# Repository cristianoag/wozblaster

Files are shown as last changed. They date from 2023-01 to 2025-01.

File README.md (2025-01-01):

# The Wozblaster (Reloaded)

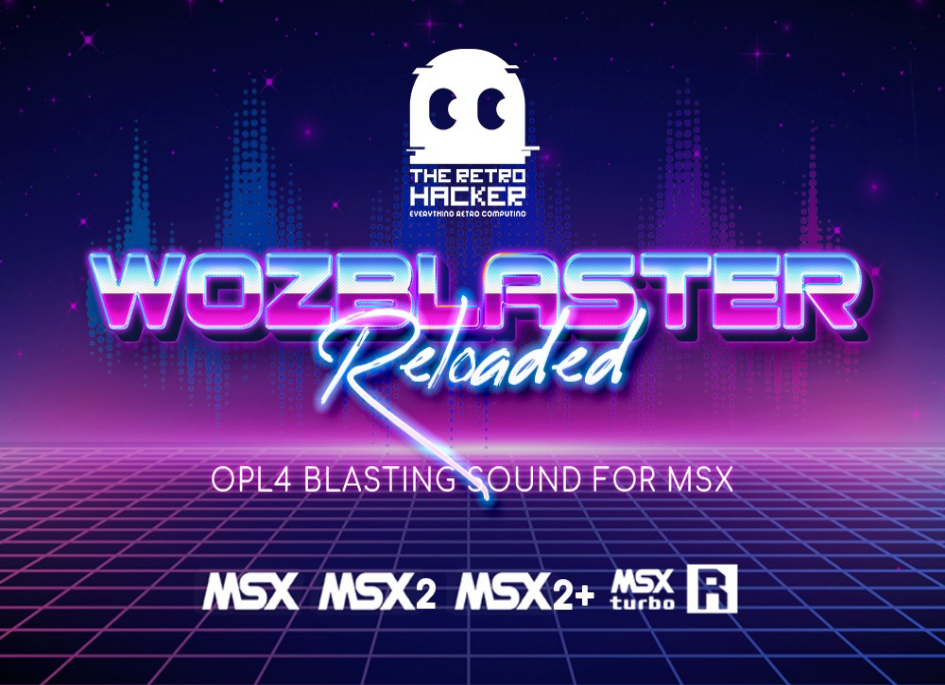
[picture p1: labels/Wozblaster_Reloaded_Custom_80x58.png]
Label


## Introduction 
The WozBlaster OPL4 cartridge is a sound expansion device designed for the MSX platform. This cartridge enables a range of additional audio capabilities for the MSX, including support for both FM synthesis and wavetable synthesis. 

At its core is the OPL4 (FM Operator Type-L4) sound chip, which was developed by Yamaha and used in a variety of electronic musical instruments and computer sound cards. 

With the WozBlaster OPL4 cartridge, MSX computer users can enjoy high-quality sound and create complex musical arrangements with ease.

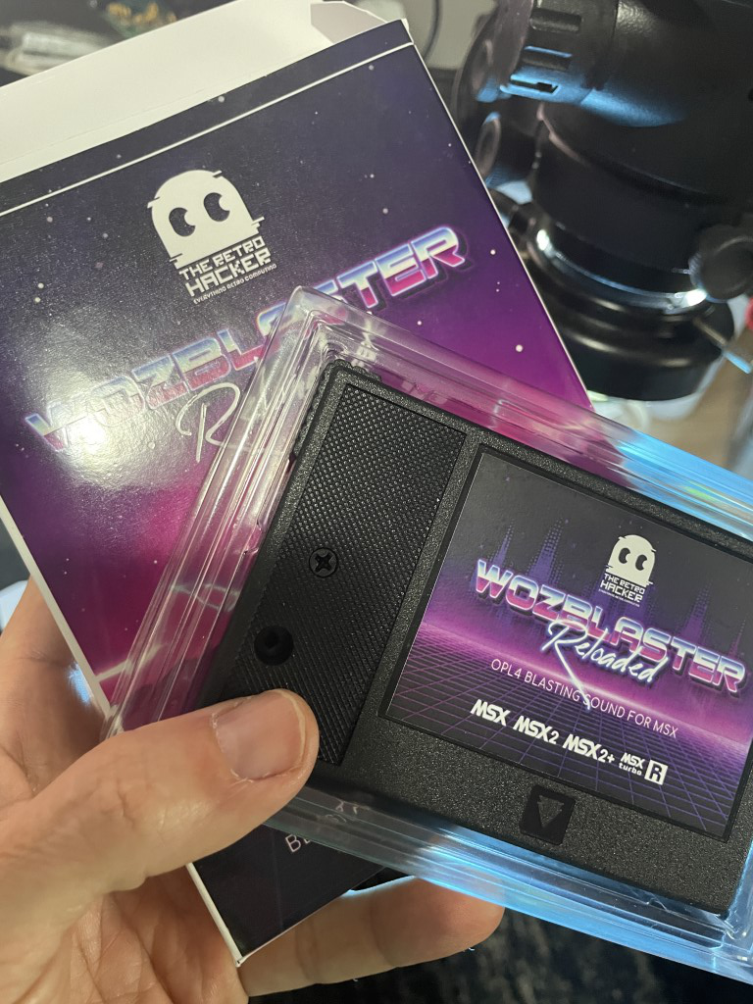
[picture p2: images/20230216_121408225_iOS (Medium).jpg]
The Wozblaster Reloaded Cartridge


The WozBlaster cartridge is an external sound device designed for the MSX platform. It is a clone of the Moonsound and allows access to the advanced capabilities of the OPL4 sound chip for MSX games and other OPL4-compatible music software. The cartridge was originally designed by Gustavo Iriarte.

The OPL4 sound chip from Yamaha is typically paired with a YAC513 floating-point DAC chip, or an alternative compatible DAC chip. The YMF278 is an enhanced version of the OPL3 and, although not officially part of the standard, has been widely adopted by the MSX community, particularly in Europe.

Moonsound clones generally come equipped with 1 MB of sample-RAM and a 2 MB Yamaha YRW801-M General MIDI ROM. Although the board has the capacity to address more than 1 MB of memory, the original version of the Wozblaster only had two 512K memory chips.

It's worth noting that the original Wozblaster PCB cannot be fitted into a traditional MSX cartridge case. Additionally, as detailed in the building instructions, the audio jack holes on the original board are quite small, which made it difficult to find a connector that would fit.

## Original Wozblaster

Image below shows the original Wozblaster cartridge PCB:

|PCB Side 1|PCB Side 2|
|---|---|
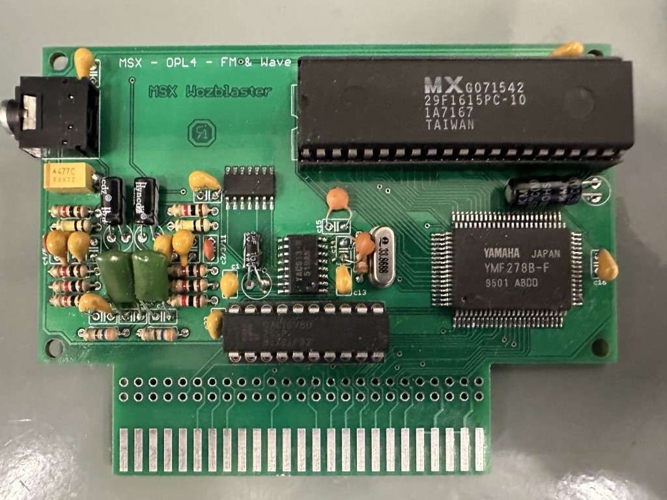
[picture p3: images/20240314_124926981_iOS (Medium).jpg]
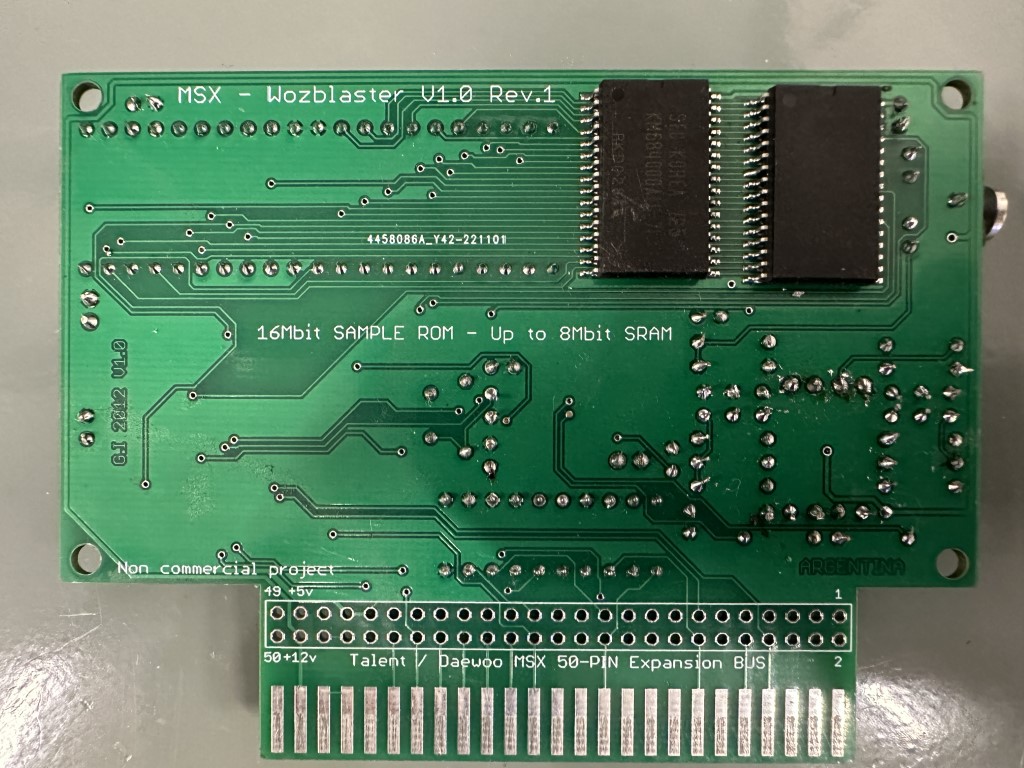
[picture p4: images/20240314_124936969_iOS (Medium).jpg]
|||

A few reloaded versions of the WozBlaster cartridge have been created with appropriately-sized holes to fit both Konami and Patola cartridge cases. Additionally, the audio jack holes have been enlarged to accommodate most common audio jack connectors. Some versions of the cartridge are still a work in progress.

## Reloaded Versions

Currently, the following versions of the WozBlaster cartridge are available (please note that this list is subject to change as new versions become available):

* [Wozblaster Reloaded v1.1](/hardware/reloaded_v1.1) - Based on the original circuit, this version features a combination of through-hole and surface-mount components. The board is smaller and can fit in both Konami and Patola cases. (tested and working)

|PCB Side 1|PCB Side 2|
|---|---|
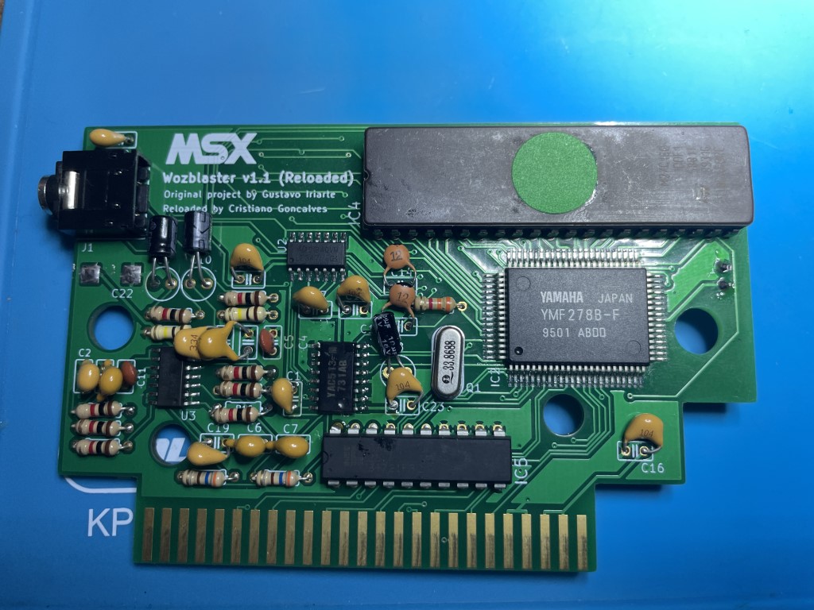
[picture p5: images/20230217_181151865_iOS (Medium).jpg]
The Wozblaster Reloaded PCB
||The Wozblaster Reloaded PCB|

* [Wozblaster Reloaded v1.3](/hardware/reloaded_v1.3) - This version replaces the old 27C160 EPROM with an AM29F016B flash memory, and all passive components are 0603 SMD. The sound is injected back to SOUNDIN in mono. The board is smaller and can fit in both Konami and Patola cases. (abandoned)
  
* [Wozblaster Reloaded v3.3](/hardware/reloaded_v3.3/) - Version based on the UDA1334 DAC, and using the [Adafruit A1334 DAC Module](https://github.com/adafruit/Adafruit-UDA1334A-I2S-Stereo-DAC-PCB) to perform the digital to analog conversion. It is injecting audio back into the SOUNDIN MSX pin. It features 1MB of RAM and 2MB of ROM with MIDI compatible samples. (tested and working)

|PCB Side 1|PCB Side 2|
|---|---|
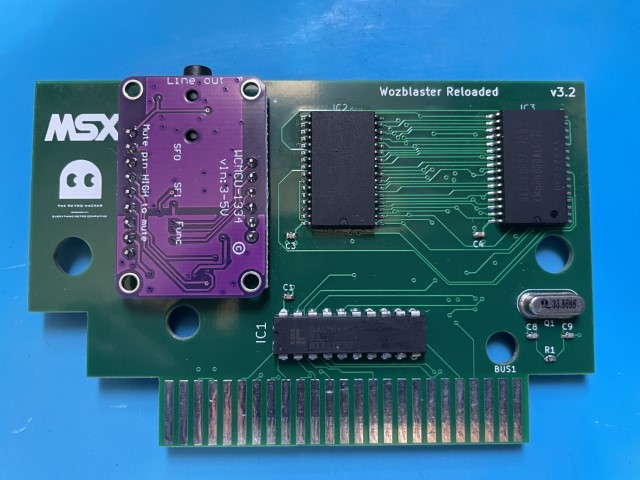
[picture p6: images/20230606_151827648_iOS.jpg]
The Wozblaster Reloaded 3.3 PCB Side 1
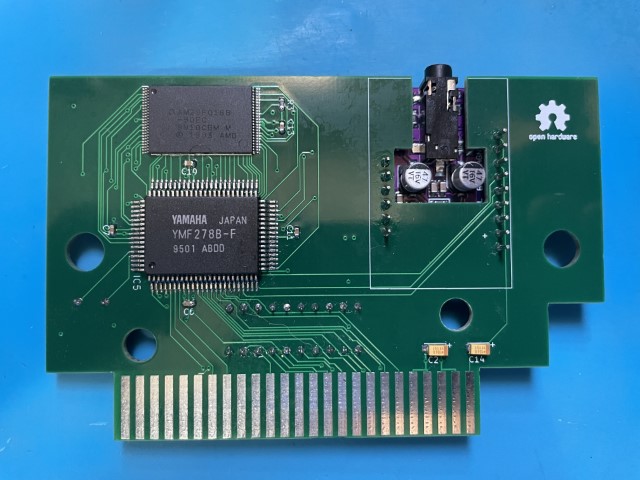
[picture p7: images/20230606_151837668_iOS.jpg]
The Wozblaster Reloaded 3.3 PCB Side 2
|||

* [Wozblaster Reloaded v4.0](/hardware/reloaded_v4.0/) - Evolution of v3.3 featuring a 2MB CY62167ELL RAM integrated. It also mixes the computer SOUNDIN. (tested and working)

|PCB Side 1|PCB Side 2|
|---|---|
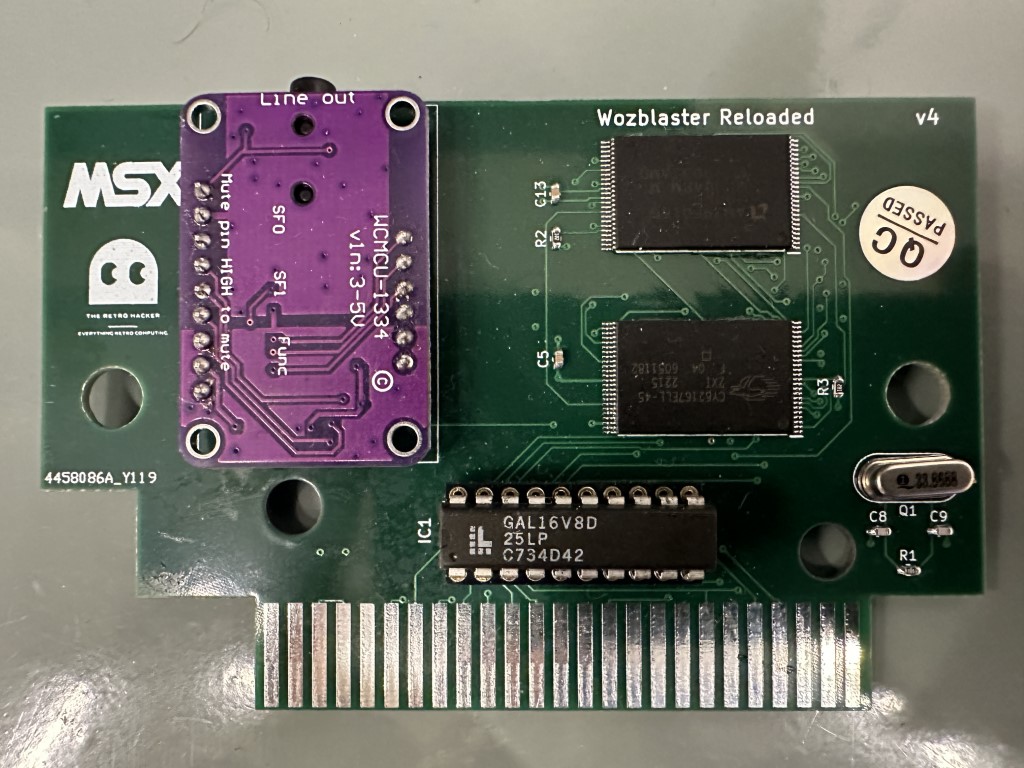
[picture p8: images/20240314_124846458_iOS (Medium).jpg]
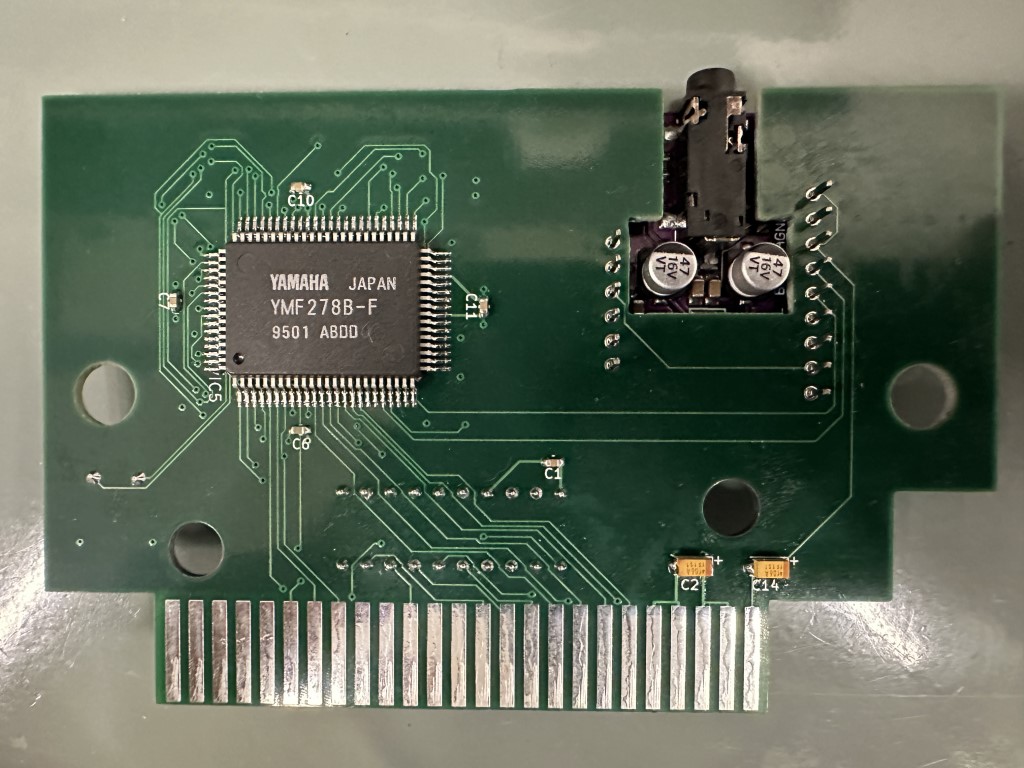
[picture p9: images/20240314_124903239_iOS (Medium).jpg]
|||

* [Wozblaster Reloaded v4.5](/hardware/reloaded_v4.5/) - This version is now using the EPM7064STC44 (or EPM7032STC400) CPLD to replace the GAL16V8D it also better isolates the audio channels  before injecting them as mono back to the MSX SOUNDIN. (tested and working)

|PCB Side 1|PCB Side 2|
|---|---|
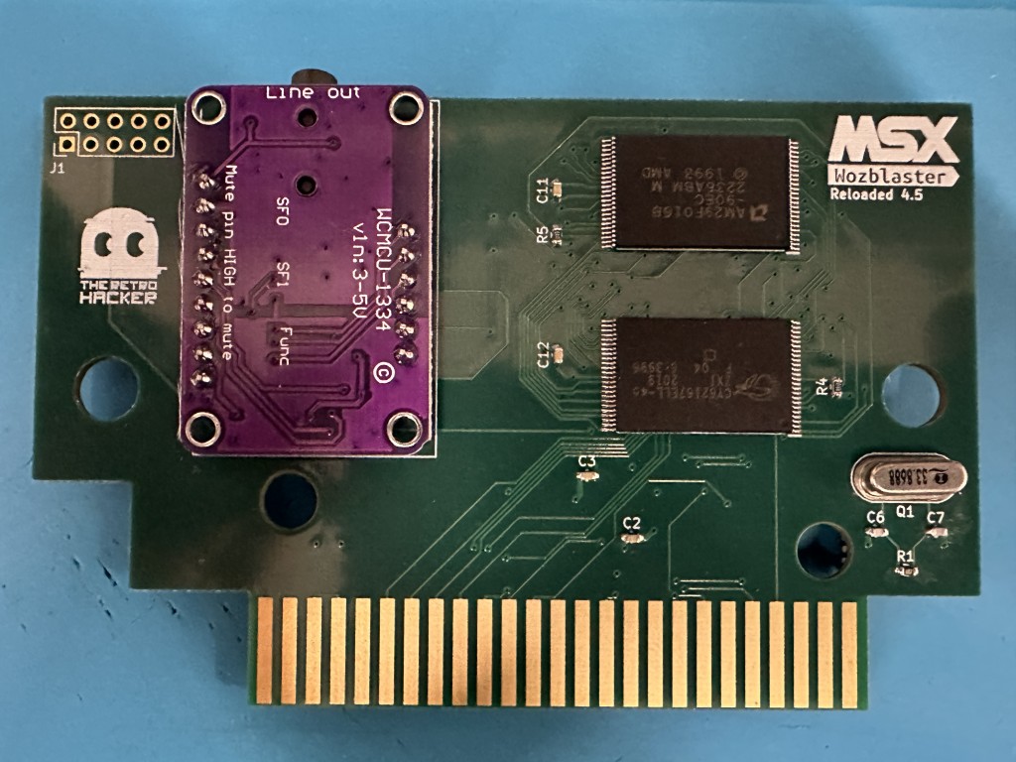
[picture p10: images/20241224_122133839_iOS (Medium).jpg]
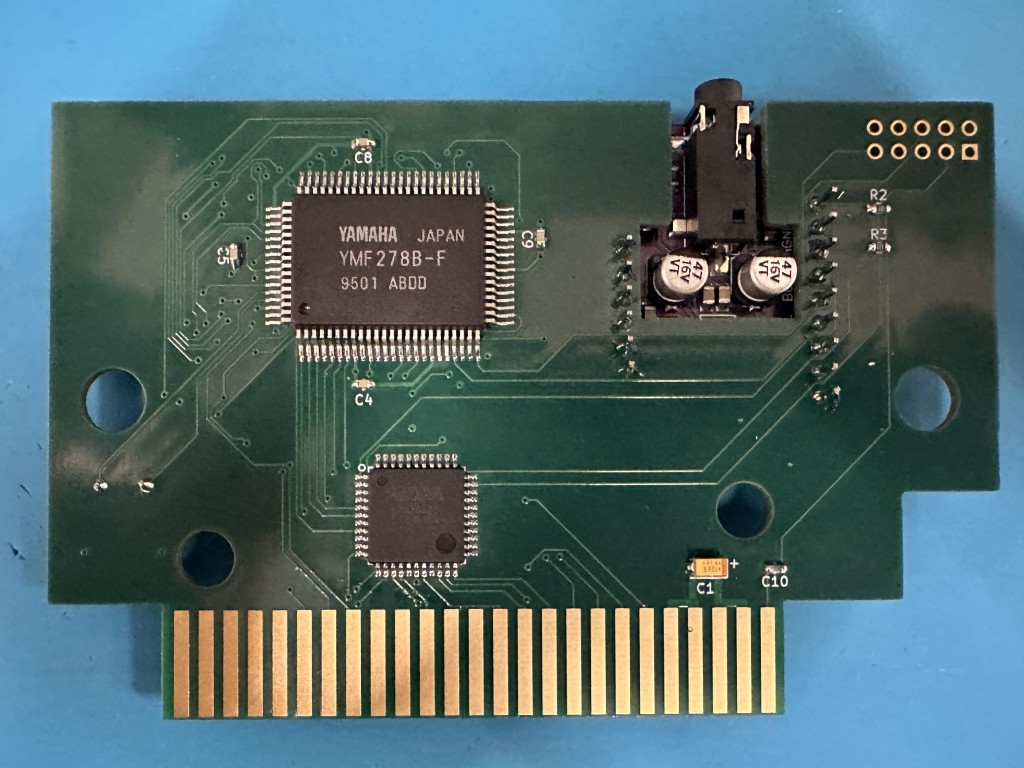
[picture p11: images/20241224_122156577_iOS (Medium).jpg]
|||

## Bill of Materials

The Bill of Materials (BOM) for each version of the WozBlaster cartridge is available in the respective page. The BOM includes a list of all the components needed to build the cartridge, as well as links to purchase the components online.

## Box and Inlay Trays

The Wozblaster Reloaded has a box designed by Adriano Souza to fit the cartridge. The box is available in the [box](/box) folder.

Although a paper inlay is provided to secure the cartridge inside the box, it is  recommended to use a plastic insert inner tray (bed) for additional protection, especially during transportation. These trays can be purchased from AliExpress at the following link: [AliExpress Tray](https://s.click.aliexpress.com/e/_DDVBv2D).

## Resources

This GitHub repository contains all of the resources needed to build both the original WozBlaster cartridge and the reloaded versions. For detailed instructions, you can refer to the article I wrote, which includes an updated bill of materials (BOM) with links to purchase the required components. You can find the article at https://theretrohacker.com/2022/12/31/blasting-sound-for-your-msx-the-wozblaster-reloaded/.

The update on the v3.1 development has been posted on a short YouTube video in english [here](https://youtu.be/J95RrFSF2NM). 

The update on v3.2 is available on a quick video [here](https://www.youtube.com/shorts/V5VmL33uvzE). 

Each folder contains detailed Bill of Materials for each version of the board, as well as the Gerber files needed to manufacture the PCBs. 

## License 

Open Hardware

This work is licensed under a [Creative Commons Attribution-NonCommercial-ShareAlike 4.0 International License](http://creativecommons.org/licenses/by-nc-sa/4.0/).

* If you remix, transform, or build upon the material, you must distribute your contributions under the same license as the original.
* You may not use the material for commercial purposes.
* You must give appropriate credit, provide a link to the license, and indicate if changes were made. You may do so in any reasonable manner, but not in any way that suggests the licensor endorses you or your use.

**ATTENTION**

This project was made for the retro community and not for commercial purposes. So only retro hardware forums and individual people can build this project.

THE SALE OF ANY PART OF THIS PROJECT WITHOUT EXPRESS AUTHORIZATION IS PROHIBITED!

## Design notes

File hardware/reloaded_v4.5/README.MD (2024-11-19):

# The Wozblaster Reloaded v4.5

- Interactive bill of materials: [BOM](https://htmlpreview.github.io/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)
- Adafruit UDA1334 module - https://github.com/adafruit/Adafruit-UDA1334A-I2S-Stereo-DAC-PCB
- Gerber Files [MSX_OPL4_Wozblaster_Reloaded_4.5.zip](/MSX%20OPL4%20Wozblaster/production/MSX_OPL4_Wozblaster_Reloaded_5.0.zip)

## Bill of Materials - Purchase List

|References|Value|Footprint|Quantity|Link|
|---|-----|---|---|----|
|C2, C3, C4, C5, C8, C9, C11, C12|0.1uF|C_0603_1608Metric|	8|[Ali Express](https://s.click.aliexpress.com/e/_DmZ8Brh)|
|C6, C7|12pF	|C_0603_1608Metric	|2|[Ali Express](https://s.click.aliexpress.com/e/_DmZ8Brh)|
|C1|	10uF/10v	|CP_EIA-3216-18_Kemet-A|	1|[Ali Express](https://s.click.aliexpress.com/e/_DDWaCDp)|
|R2, R3	|330R|R_0603_1608Metric	|2|[Ali Express](https://s.click.aliexpress.com/e/_DDKvQnz)|
|R4, R5	|1K	|R_0603_1608Metric	|5|[Ali Express](https://s.click.aliexpress.com/e/_DDKvQnz)|
|R1	|3.3K|	R_0603_1608Metric	|1|[Ali Express](https://s.click.aliexpress.com/e/_DDKvQnz)|
|U1|EPM7064STC44-7 (or EPM7032STC44)|QFP80P1200X1200X120-44N	|1|[Ali Express](https://s.click.aliexpress.com/e/_DkdMPh3)|
|U2	|UDA1334MOD	|UDA1334MOD	|1|[Ali Express](https://www.aliexpress.com/item/1005003524298218.html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)|
|U3	|YMF278B-F|	80-QFP|1|[The Retro Hacker Store](https://theretrohacker.com/shop)|
|U4	|AM29F016B-120EC|	SOP50P2000X120-48N	|1|[Ali Express](https://s.click.aliexpress.com/e/_Dm44l5V)|
|U5	|CY62167ELL|	SOP50P2000X120-48N	|1|[Ali Express](https://s.click.aliexpress.com/e/_DkopT8T)|
|Q1	|33.8688|	Crystal_HC49-U_Vertical|1|[Ali Express](https://s.click.aliexpress.com/e/_DlvdCQT)|
|J1|AVR-JTAG-10	|PinHeader_2x05_P2.54mm_Vertical	|1|[Ali Express](https://s.click.aliexpress.com/e/_DFQLUzR)|

## CPLD Code

The Wozblaster Reloaded 4.5 uses a EPM7064STC44 (or EPM7032STC44) CPLD. The code is available in the `cpld` folder. The code was written in Verilog and compiled using the Quartus II software. The compiled file `msx_opl4.pof` is also available in the `cpld` folder. Please use the appropriate version depending on the CPLD you selected.

It implements the selection of the OPL4 chip and its registers. 

The I/O of the OPL4 can be done on the following I/O ports:

|Port|Binary|Function|
|-----|---|----|
|07Eh |01111110 | wave register	|
|07Fh |01111111 | wave data|				
|0C4h |11000100 | FM bank 1 register|
|0C5h |11000101 | FM data|
|0C6h |11000110 | FM bank 2 register|

0C7h is a mirror of the FM data register but use of 0C5h is preferred.

The selection of the EPM7064STC44 (or EPM7032STC44) CPLD was due to the fact that it is a common CPLD supporting 5V and can be found in several sources. It is also less subject to JTAG locking than other versions of those CPLDs based on PLCC. The 
EPM7032STC44 can also be used as it is pin compatible with the EPM7064STC44 and the size of synthesis is small enough to fit in the EPM7032STC44.

## SOUNDIN

The SOUNDIN signal for the MSX computer is obtained by combining the two stereo channels into a single mono channel over a set of resistors a a filter capacitor. 

## License
Open Hardware

This work is licensed under a [Creative Commons Attribution-NonCommercial-ShareAlike 4.0 International License](http://creativecommons.org/licenses/by-nc-sa/4.0/).

* If you remix, transform, or build upon the material, you must distribute your contributions under the same license as the original.
* You may not use the material for commercial purposes.
* You must give appropriate credit, provide a link to the license, and indicate if changes were made. You may do so in any reasonable manner, but not in any way that suggests the licensor endorses you or your use.

**ATTENTION**

This project was made for the retro community and not for commercial purposes. So only retro hardware forums and individual people can build this project.

THE SALE OF ANY PART OF THIS PROJECT WITHOUT EXPRESS AUTHORIZATION IS PROHIBITED!

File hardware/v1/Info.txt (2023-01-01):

Wozblaster V1.0 Rev.1

Se corrigió:

- Texto erróneo +5V / +12v que estaban invertidos.
- Se corrió 1mm hacia borde perforación masa jack audio.
- Texto c2/3/12 por c2/3/11.

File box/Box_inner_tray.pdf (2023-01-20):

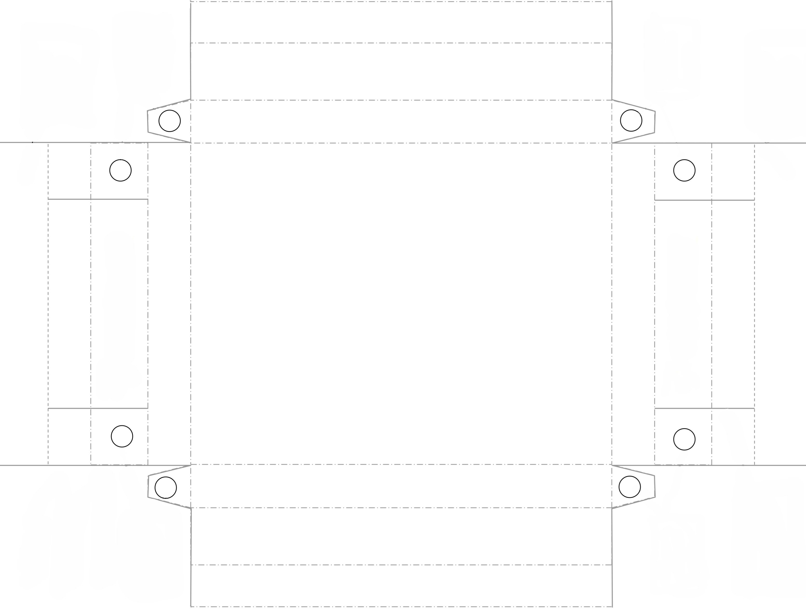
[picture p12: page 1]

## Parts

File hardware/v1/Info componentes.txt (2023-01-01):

100nF ceramico

c13
c16
c17
c19
c18
c20
c23

---------------------

4.7uF 16v

c21

---------------------

10uF x 16v

c8

---------------------

22uF x 16v

c9
c10

---------------------

12p ceramico

c14
c15

---------------------

10p ceramico

c1

---------------------

2200p ceramico

c6
c7
c5
c3

---------------------

0.015uF ceramico

c4
c11

---------------------

0.33uF ceramico

c12
c2

---------------------

470uF x 16v

c22

---------------------

OPL4: Yamaha YMF278B-F

DAC: Yamaha YAC513-M

Op-Amps: LF347

SRAM: KM684000ALG

EPROM: 27c160

GAL: Lattice 16V8D

Cristal: 33.8688

1 Jack audio stereo

---------------------

8r x 1K
2r x 360ohm
2r x 100k
1r x 3.3k

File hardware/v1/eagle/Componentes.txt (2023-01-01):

List of components:

1 x PCB
1 x YMF278B-F or YMF268-F
1 x YAC513-M (SOP16)
2 x LF347 (SOP14)
1 x GAL16V8D (DIP20)
1 x 27C160 EPROM (DIP42)
2 x KM684000ALG (512kB) (SOP32)
1 x Cristal 33.8688 (HC49-S)
7 x 100nF cerámic / multilayer  2.5 mm or less
4 x 2200pF cerámic 2.5 mm or less
2 x 12pF cerámic  2.5 mm or less
1 x 10pF cerámic  2.5 mm or less
2 x 0.015uF cerámic  2.5 mm or less
2 x 0.033uF cerámic  2.5 mm or less
1 x 3.3K 1/4
8 x 1K 1/4
2 x 100K 1/4
2 x 360ohm 1/4
1 x 4.7uF 16v 
1 x 10uF 16v  
2 x 22uF 16v  
1 x Jack Audio Estereo para chasis 1/4
C22,470uFx16v tantalum not necessary.

Avoid use of used 27c160, try to use only new ones due to programming failure.

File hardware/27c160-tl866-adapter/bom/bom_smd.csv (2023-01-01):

Component | Part | References | Value | MPN | Quantity Per PCB | Datasheet
1 | BC327 | Q1 | MMBT3906 | MMBT3906-7-F | 1 | https://media.digikey.com/pdf/Data%20Sheets/Diodes%20PDFs/MMBT3906.pdf
2 | R-EU_0207_10 | R1 R2 R3 R4 R5 | 10k | RC1206JR-0710KP | 5 | http://www.yageo.com/NewPortal/yageodocoutput?fileName=/pdf/R-Chip/PYu-RC_51_RoHS_P_0.pdf
3 | SW_DIP-3 | SW2 | DIP | BD03 | 1 | https://www.ckswitches.com/media/1331/bd.pdf
4 | MS22D16 | SW1 | MS22D16 | JS202011CQN | 1 | https://www.ckswitches.com/media/1422/js.pdf
5 | 27C4002 | U1 | 27C4002 | 61302011121 | 2 | https://katalog.we-online.de/em/datasheet/6130xx11121.pdf
6 | 3M_248-3345 | ZX1 | 3M_248-3345 | 248-1282-00-0602J | 1 | http://multimedia.3m.com/mws/media/494546O/3mtm-dip-sockets-100-2-54-mm-ts0365.pdf

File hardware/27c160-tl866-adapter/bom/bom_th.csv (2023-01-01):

Component | Part | References | Value | MPN | Quantity Per PCB | Datasheet
1 | BC327 | Q1 | BC327 | BC327 | 1 | https://media.digikey.com/pdf/Data%20Sheets/ON%20Semiconductor%20PDFs/BC327%20Rev3.pdf
2 | R-EU_0207_10 | R1 R2 R3 R4 R5 | 10k | CFR-25JB-52-10K | 5 | http://www.yageo.com/NewPortal/yageodocoutput?fileName=/pdf/throughhole/Yageo_LR_CFR_2013.pdf
3 | SW_DIP-3 | SW2 | DIP | BD03 | 1 | https://www.ckswitches.com/media/1331/bd.pdf
4 | MS22D16 | SW1 | MS22D16 | JS202011CQN | 1 | https://www.ckswitches.com/media/1422/js.pdf
5 | 27C4002 | U1 | 27C4002 | 61302011121 | 2 | https://katalog.we-online.de/em/datasheet/6130xx11121.pdf
6 | 3M_248-3345 | ZX1 | 3M_248-3345 | 248-1282-00-0602J | 1 | http://multimedia.3m.com/mws/media/494546O/3mtm-dip-sockets-100-2-54-mm-ts0365.pdf

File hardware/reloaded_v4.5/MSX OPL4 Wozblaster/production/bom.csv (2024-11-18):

Designator | Footprint | Quantity | Value | LCSC Part #
C1 | CP_EIA-3216-18_Kemet-A | 1 | 10uF/10v
C10 | 0603 | 1 | 10uF
C11, C12, C2, C3, C4, C5, C8, C9 | 0603 | 8 | 0.1uF
C6, C7 | 0603 | 2 | 12pF
J1 | PinHeader_2x05_P2.54mm_Vertical | 1 | AVR-JTAG-10
Q1 | Crystal_HC49-U_Vertical | 1 | 33.8688
R1 | 0603 | 1 | 3.3K
R2, R3 | 0603 | 2 | 330R
R4, R5 | 0603 | 2 | 1K
U1 | QFP80P1200X1200X120-44N | 1 | EPM7064STC44-7 | EPM7064STC44-7
U2 | UDA1334MOD | 1 | UDA1334MOD
U3 | 80-QFP | 1 | YMF278B-F
U4 | SOP50P2000X120-48N | 1 | AM29F016B-120EC
U5 | SOP50P2000X120-48N | 1 | CY62167ELL

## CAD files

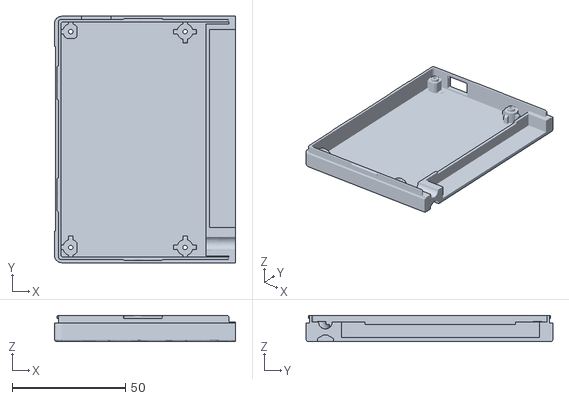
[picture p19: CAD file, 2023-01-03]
cases/Wozblaster V1 1.2_bottom.stl
80.0 x 109.0 x 11.6

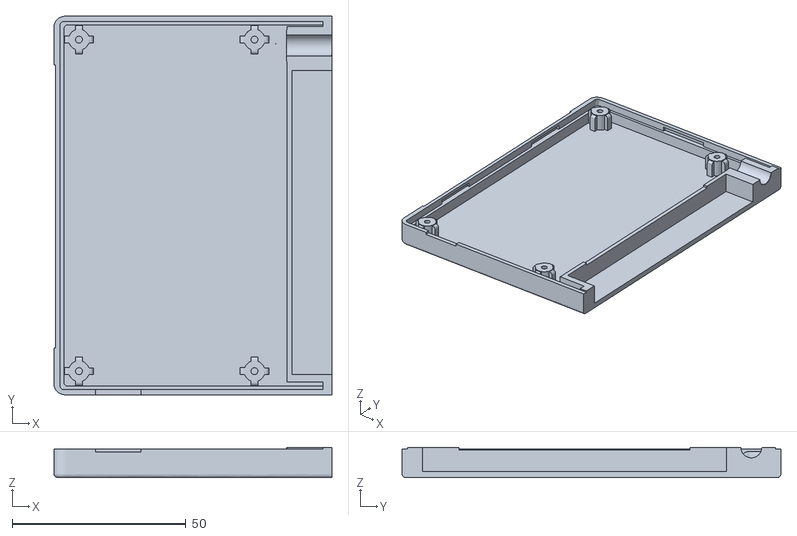
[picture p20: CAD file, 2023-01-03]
cases/Wozblaster V1 1.2_top.stl
80.0 x 109.0 x 8.65

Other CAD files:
cases/Wozblaster V1 1.1_top.stl
cases/Wozblaster V1 1.1_bottom.stl
cases/_old/Wozblaster V1 1.1_bottom.stl
cases/_old/Wozblaster V1 1.1_top.stl

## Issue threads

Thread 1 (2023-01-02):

Both versions (v1 and reloaded) are not driving the soundin

cristianoag, 2023-01-02:
Both versions are not driving the mono soundin signal on the cartridge slot. There is documentation available at http://www.msxpro.com/wozblaster.html showing what needs to be done to the circuit to support that.

cristianoag, 2023-04-21:
Fixed on v3.1

Closed 2023-04-21.

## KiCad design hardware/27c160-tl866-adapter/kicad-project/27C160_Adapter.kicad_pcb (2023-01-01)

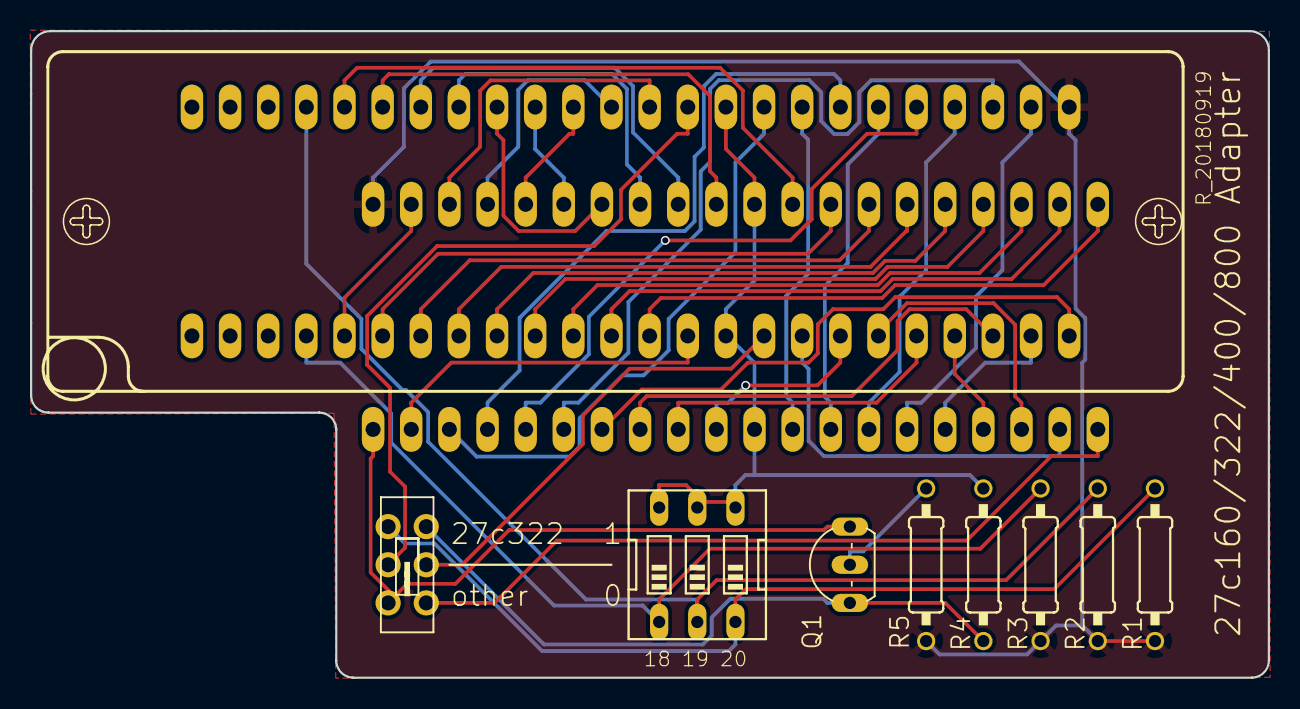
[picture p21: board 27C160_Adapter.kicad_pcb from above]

Board: 2 copper layers, 82.4 x 43.1 mm, 12 parts (0 on the bottom side), 46 nets.

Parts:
G001: LOGO; mini-mods
Q1: BC327; TO92-EBC
R1, R2, R3, R4, R5: 10k; 0207%2f10
REF01: OSHW-Logo2_9.8x8mm_SilkScreen
SW1: MS22D16
SW2: DIP; EDG-03
U1: 27C4002
ZX1: 3M_248-3345

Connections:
/A0: U1.21, ZX1.13
/A1: U1.22, ZX1.12
/A2: U1.23, ZX1.11
/A3: U1.24, ZX1.10
/A4: U1.25, ZX1.9
/A5: U1.26, ZX1.8
/A6: U1.27, ZX1.7
/A7: U1.28, ZX1.6
/A8: U1.29, ZX1.44
/A9: U1.31, ZX1.43
/A10: U1.32, ZX1.42
/A11: U1.33, ZX1.41
/A12: U1.34, ZX1.40
/A13: U1.35, ZX1.39
/A14: U1.36, ZX1.38
/A15: U1.37, ZX1.37
/A16: U1.38, ZX1.36
/A17: U1.39, ZX1.5
/A18: R3.1, SW2.1, ZX1.4
/A19: R2.1, SW2.2, ZX1.45
/A20: R1.1, SW1.3, SW2.3
/D0: U1.19, ZX1.17
/D1: U1.18, ZX1.19
/D2: U1.17, ZX1.21
/D3: U1.16, ZX1.23
/D4: U1.15, ZX1.26
/D5: U1.14, ZX1.28
/D6: U1.13, ZX1.30
/D7: U1.12, ZX1.32
/D8: U1.10, ZX1.18
/D9: U1.9, ZX1.20
/D10: U1.8, ZX1.22
/D11: U1.7, ZX1.24
/D12: U1.6, ZX1.27
/D13: U1.5, ZX1.29
/D14: U1.4, ZX1.31
/D15: U1.3, ZX1.33
/E: U1.2, ZX1.14
/N$1: Q1.B, R5.2
/N$2: SW1.2, ZX1.35
/N$4: Q1.C, R4.2, SW1.6
/N$5: SW1.4, U1.20
/N$6: SW1.5, ZX1.16
/VPP: Q1.E, SW1.1, U1.1
GND: R4.1, SW2.4, SW2.5, SW2.6, U1.11, U1.30, ZX1.15, ZX1.34
VCC: R1.2, R2.2, R3.2, R5.1, U1.40, ZX1.25

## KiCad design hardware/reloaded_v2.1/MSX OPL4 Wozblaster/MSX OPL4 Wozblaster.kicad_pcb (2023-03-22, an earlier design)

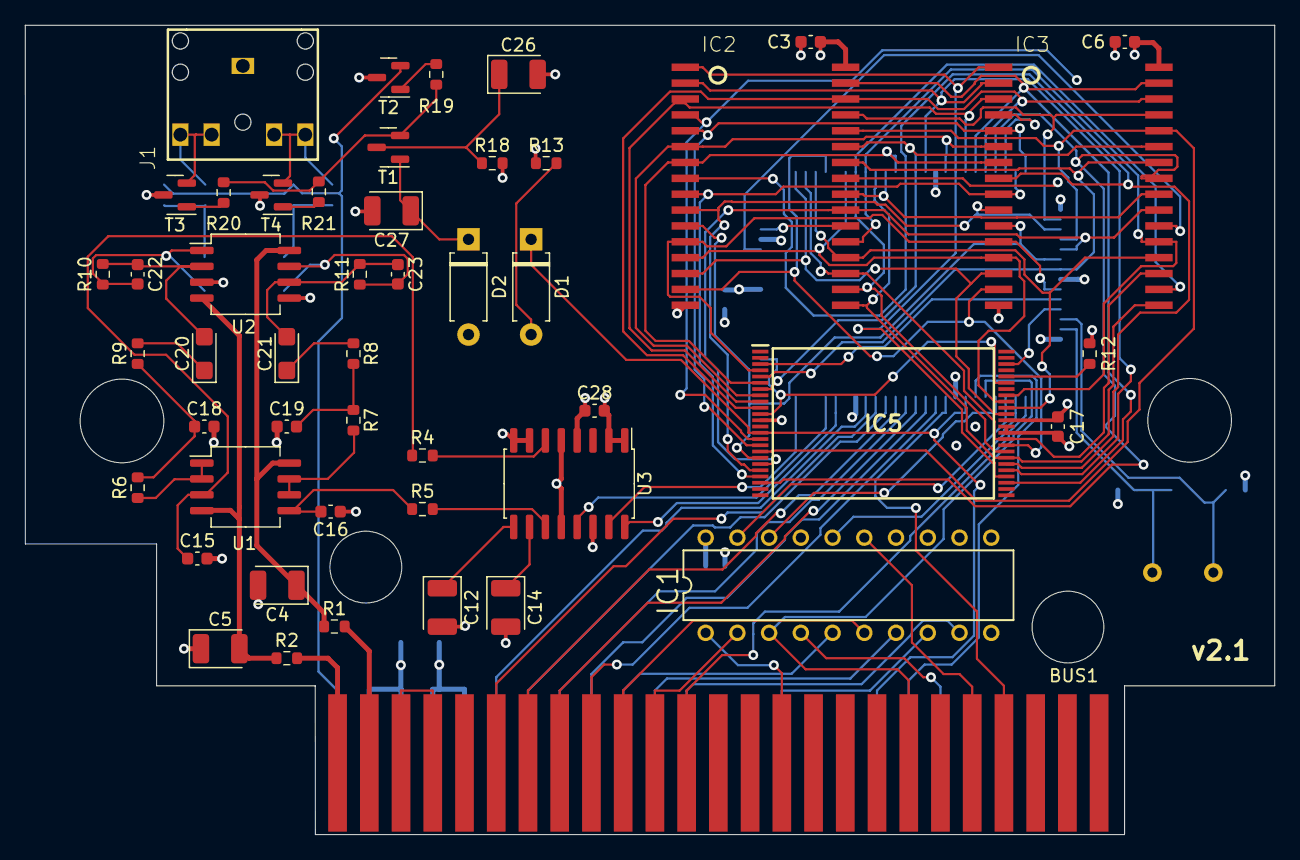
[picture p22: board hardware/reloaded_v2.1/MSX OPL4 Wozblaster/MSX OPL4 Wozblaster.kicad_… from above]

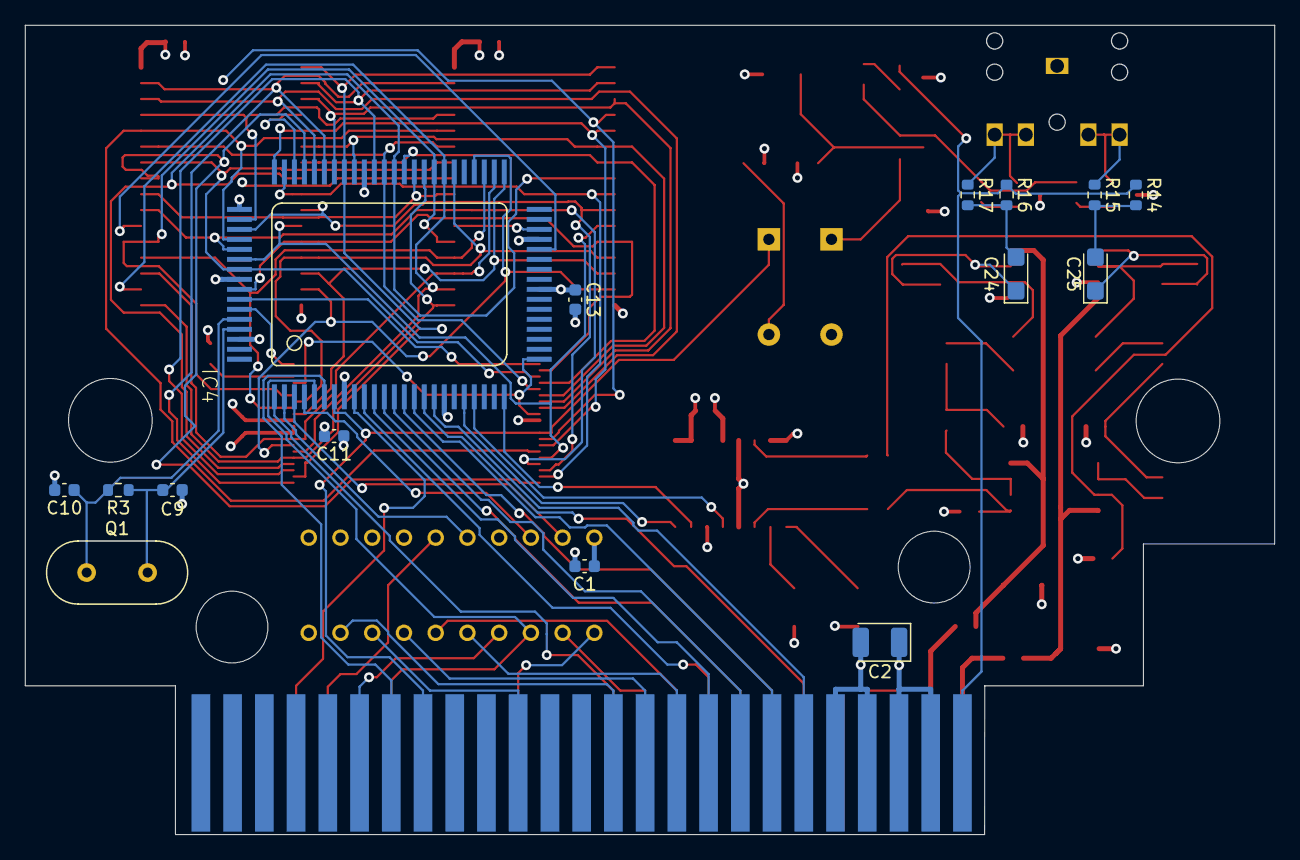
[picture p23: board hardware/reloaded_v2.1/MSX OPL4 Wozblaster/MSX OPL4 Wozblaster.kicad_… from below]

Board: 4 copper layers, 100.0 x 64.8 mm, 64 parts (15 on the bottom side), 100 nets.

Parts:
BUS1: MSX_SLOT_EDGE-CON; msx_cartridge
C1, C3, C6, C11, C13, C17, C28: 0.1uF; C_0603_1608Metric
C2: 10uF/16V; CP_EIA-3528-21_Kemet-B
C4, C5: 47uF 16V; CP_EIA-3528-21_Kemet-B
C9, C10: 12pF; C_0603_1608Metric
C12, C14: 47uF; CP_EIA-3528-21_Kemet-B
C15, C16, C18, C19: 1nF; C_0603_1608Metric
C20, C21, C24, C25: 4.7uF 25V; CP_EIA-3216-18_Kemet-A
C22, C23: 390pF; C_0603_1608Metric
C26, C27: 22uF 10V; CP_EIA-3528-21_Kemet-B
D1, D2: D; D_A-405_P7.62mm_Horizontal
IC1: GAL16V8D; DIL20
IC2, IC3: KM684000ALG; SOP32L
IC4: YMF278B-F; 80-QFP
IC5: AM29F016B-120EC; SOP50P2000X120-48N
J1: PJ-307
Q1: 33.8688; Crystal_HC49-U_Vertical
R1, R2: 220R; R_0603_1608Metric
R3: 3.3K; R_0603_1608Metric
R4, R5, R13, R18: 10K; R_0603_1608Metric
R6, R7, R8, R9: 4.7K; R_0603_1608Metric
R10, R11: 100K; R_0603_1608Metric
R12, R14, R16: 1K; R_0603_1608Metric
R15, R17: 1.8K; R_0603_1608Metric
R19, R20, R21: 2.2K; R_0603_1608Metric
T1: 2SA733; SOT-23
T2, T3, T4: 2SC945; SOT-23
U1, U2: NJM4558; SO-8_5.3x6.2mm_P1.27mm
U3: uPD6376; SO-16_5.3x10.2mm_P1.27mm

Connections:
+5V: BUS1.45 (+5V), BUS1.47 (+5V), C1.1, C2.1 (+), C3.1, C6.1, C11.1, C13.1, C17.1, C28.1, D2.2 (A), IC1.20 (VCC), IC2.32 (VCC), IC3.32 (VCC), IC4.8 (VCC), IC4.32 (VCC@1), IC4.55 (VCC@2), IC4.72 (VCC@3), IC5.12 (VCC_1), IC5.37 (VCC_2), R12.1, R13.1, R18.2, U3.4 (D.VDD), U3.7 (A.VDD), U3.8 (A.VDD)
+12V: BUS1.48 (+12V), R1.2
-12V: BUS1.50 (-12V), R2.2
/A0: IC2.8 (A4), IC3.8 (A4), IC4.52 (MA0), IC5.30 (A0)
/A1: IC2.2 (A16), IC3.2 (A16), IC4.54 (MA1), IC5.29 (A1)
/A2: IC2.1 (A18), IC3.1 (A18), IC4.57 (MA2), IC5.28 (A2)
/A3: IC2.31 (A15), IC3.31 (A15), IC4.59 (MA3), IC5.27 (A3)
/A4: IC2.25 (A11), IC3.25 (A11), IC4.61 (MA4), IC5.22 (A4)
/A5: IC2.9 (A3), IC3.9 (A3), IC4.63 (MA5), IC5.21 (A5)
/A6: IC2.10 (A2), IC3.10 (A2), IC4.67 (MA6), IC5.20 (A6)
/A7: IC2.23 (A10), IC3.23 (A10), IC4.69 (MA7), IC5.19 (A7)
/A8: IC2.11 (A1), IC3.11 (A1), IC4.70 (MA8), IC5.18 (A8)
/A9: IC2.28 (A13), IC3.28 (A13), IC4.68 (MA9), IC5.17 (A9)
/A10: IC2.5 (A7), IC3.5 (A7), IC4.64 (MA10), IC5.16 (A10)
/A11: IC2.4 (A12), IC3.4 (A12), IC4.62 (MA11), IC5.15 (A11)
/A12: IC2.30 (A17), IC3.30 (A17), IC4.60 (MA12), IC5.10 (A12)
/A13: IC2.3 (A14), IC3.3 (A14), IC4.58 (MA13), IC5.9 (A13)
/A14: IC2.6 (A6), IC3.6 (A6), IC4.56 (MA14), IC5.8 (A14)
/A15: IC2.27 (A8), IC3.27 (A8), IC4.53 (MA15), IC5.7 (A15)
/A16: IC2.7 (A5), IC3.7 (A5), IC4.51 (MA16), IC5.6 (A16)
/A17: IC2.26 (A9), IC3.26 (A9), IC4.71 (MA17), IC5.5 (A17)
/A18: IC2.12 (A0), IC3.12 (A0), IC4.73 (MA18), IC5.4 (A18)
/A19: IC4.74 (MA19), IC5.3 (A19)
/A20: IC4.75 (MA20), IC5.46 (A20)
/AA0: BUS1.28 (A0), IC4.1 (A0)
/AA1: BUS1.27 (A1), IC1.9 (I8)
/AA2: BUS1.30 (A2), IC1.2 (I1)
/AA3: BUS1.29 (A3), IC1.7 (I6)
/AA4: BUS1.32 (A4), IC1.6 (I5)
/AA5: BUS1.31 (A5), IC1.5 (I4)
/AA6: BUS1.22 (A6), IC1.1 (CLK)
/AA7: BUS1.21 (A7), IC1.8 (I7)
/D0: BUS1.34 (D0), IC4.10 (D0)
/D1: BUS1.33 (D1), IC4.11 (D1)
/D2: BUS1.36 (D2~), IC4.12 (D2)
/D3: BUS1.35 (D3), IC4.13 (D3)
/D4: BUS1.38 (D4), IC4.14 (D4)
/D5: BUS1.37 (D5), IC4.15 (D5)
/D6: BUS1.40 (D6), IC4.16 (D6)
/D7: BUS1.39 (D7), IC4.17 (D7)
/MD0: IC2.17 (O4), IC3.17 (O4), IC4.49 (MD0), IC5.31 (DQ0)
/MD1: IC2.18 (O5), IC3.18 (O5), IC4.47 (MD1), IC5.32 (DQ1)
/MD2: IC2.15 (O3), IC3.15 (O3), IC4.44 (MD2), IC5.33 (DQ2)
/MD3: IC2.19 (O6), IC3.19 (O6), IC4.42 (MD3), IC5.34 (DQ3)
/MD4: IC2.14 (O2), IC3.14 (O2), IC4.41 (MD4), IC5.38 (DQ4)
/MD5: IC2.20 (O7), IC3.20 (O7), IC4.43 (MD5), IC5.39 (DQ5)
/MD6: IC2.13 (O1), IC3.13 (O1), IC4.46 (MD6), IC5.40 (DQ6)
/MD7: IC2.21 (O8), IC3.21 (O8), IC4.48 (MD7), IC5.41 (DQ7)
/SLTSOUND: BUS1.49 (SOUNDOUT), R14.1, R16.1, T2.2 (E)
/~BUSDIR: BUS1.10 (~BUSDIR), IC1.15 (O5)
/~CS0: IC3.22 (~CS), IC4.36 (~MCS6)
/~CS1: IC2.22 (~CS), IC4.38 (~MCS7)
/~INT: BUS1.8 (~INT), IC4.9 (~IRQ)
/~IORQ: BUS1.11 (~IORQ), IC1.4 (I3)
/~MRD: IC2.24 (~OE), IC3.24 (~OE), IC4.50 (~MRD)
/~MWR: IC2.29 (~WE), IC3.29 (~WE), IC4.66 (~MWR)
/~RD: BUS1.14 (~RD), IC1.3 (I2), IC4.5 (~RD)
/~RESET: BUS1.15 (~RESET), D1.1 (K), IC4.7 (~RESET), IC5.14 (RESET#)
/~ROM: IC4.25 (~MCS0), IC5.11 (CE#), IC5.43 (OE#)
/~WR: BUS1.13 (~WR), IC4.6 (~WR)
GND: BUS1.41 (GND), BUS1.43 (GND), C1.2, C2.2 (-), C3.2, C4.2 (-), C5.1 (+), C6.2, C9.2, C10.2, C11.2, C12.2 (-), C13.2, C14.2 (-), C15.2, C16.1, C17.2, C18.2, C19.1, C26.2 (-), C27.2 (-), C28.2, IC1.10 (GND), IC1.11 (~OE), IC1.12 (O8), IC1.13 (O7), IC1.14 (O6), IC1.17 (O3), IC2.16 (GND), IC3.16 (GND), IC4.18 (GND), IC4.37 (GND@1), IC4.65 (GND@2), IC4.78 (GND@3), IC5.35 (VSS_1), IC5.36 (VSS_2), J1.1, T2.3 (C), T3.3 (C), T4.3 (C), U2.3 (+), U2.5 (+), U3.1 (4/8_fS_SEL), U3.2 (D.GND), U3.5 (A.GND), U3.12 (A.GND), U3.14 (LRSEL/RSI)
unnamed: BUS1.44 (SW1), BUS1.46 (SW2)
unnamed: C4.1 (+), R1.1, U1.8 (V+), U2.8 (V+)
unnamed: C5.2 (-), R2.1, U1.4 (V-), U2.4 (V-)
unnamed: C12.1 (+), U3.9 (R.REF)
unnamed: C14.1 (+), U3.10 (L.REF)
unnamed: C18.1, R6.2, R9.1
unnamed: C19.2, R7.1, R8.2
unnamed: C20.1 (+), R9.2
unnamed: C20.2 (-), C22.1, R10.2, U2.2 (-)
unnamed: C21.1 (+), R8.1
unnamed: C21.2 (-), C23.1, R11.2, U2.6 (-)
unnamed: C23.2, C24.1 (+), R11.1, U2.7
unnamed: C24.2 (-), R16.2, R17.2
unnamed: C22.2, C25.1 (+), R10.1, U2.1
unnamed: C25.2 (-), R14.2, R15.2
unnamed: C26.1 (+), R18.1, T1.3 (B)
unnamed: C27.1 (+), D2.1 (K), T1.1 (E)
unnamed: D1.2 (A), R13.2
unnamed: IC1.19 (O1), IC4.3 (A2)
unnamed: IC1.18 (O2), IC4.4 (~CS)
unnamed: IC1.16 (O4), IC4.2 (A1)
unnamed: IC4.20 (BCO), U3.16 (CLK)
unnamed: IC4.24 (DO2), U3.15 (SI/LSI)
unnamed: IC4.21 (LRO), U3.13 (LRCK/WDCK)
unnamed: C9.1, IC4.77 (XI), Q1.2, R3.1
unnamed: C10.1, IC4.76 (XO), Q1.1, R3.2
unnamed: IC5.44 (WE#), R12.2
unnamed: R19.2, R20.2, R21.2, T1.2 (C)
unnamed: R19.1, T2.1 (B)
unnamed: R20.1, T3.1 (B)
unnamed: J1.4, J1.5, R15.1, T3.2 (E)
unnamed: R21.1, T4.1 (B)
unnamed: J1.2, J1.3, R17.1, T4.2 (E)
unnamed: C15.1, R4.1, U1.3 (+)
unnamed: R6.1, U1.1, U1.2 (-)
unnamed: C16.2, R5.1, U1.5 (+)
unnamed: R7.2, U1.6 (-), U1.7
unnamed: R5.2, U3.11 (L.OUT)
unnamed: R4.2, U3.6 (R.OUT)

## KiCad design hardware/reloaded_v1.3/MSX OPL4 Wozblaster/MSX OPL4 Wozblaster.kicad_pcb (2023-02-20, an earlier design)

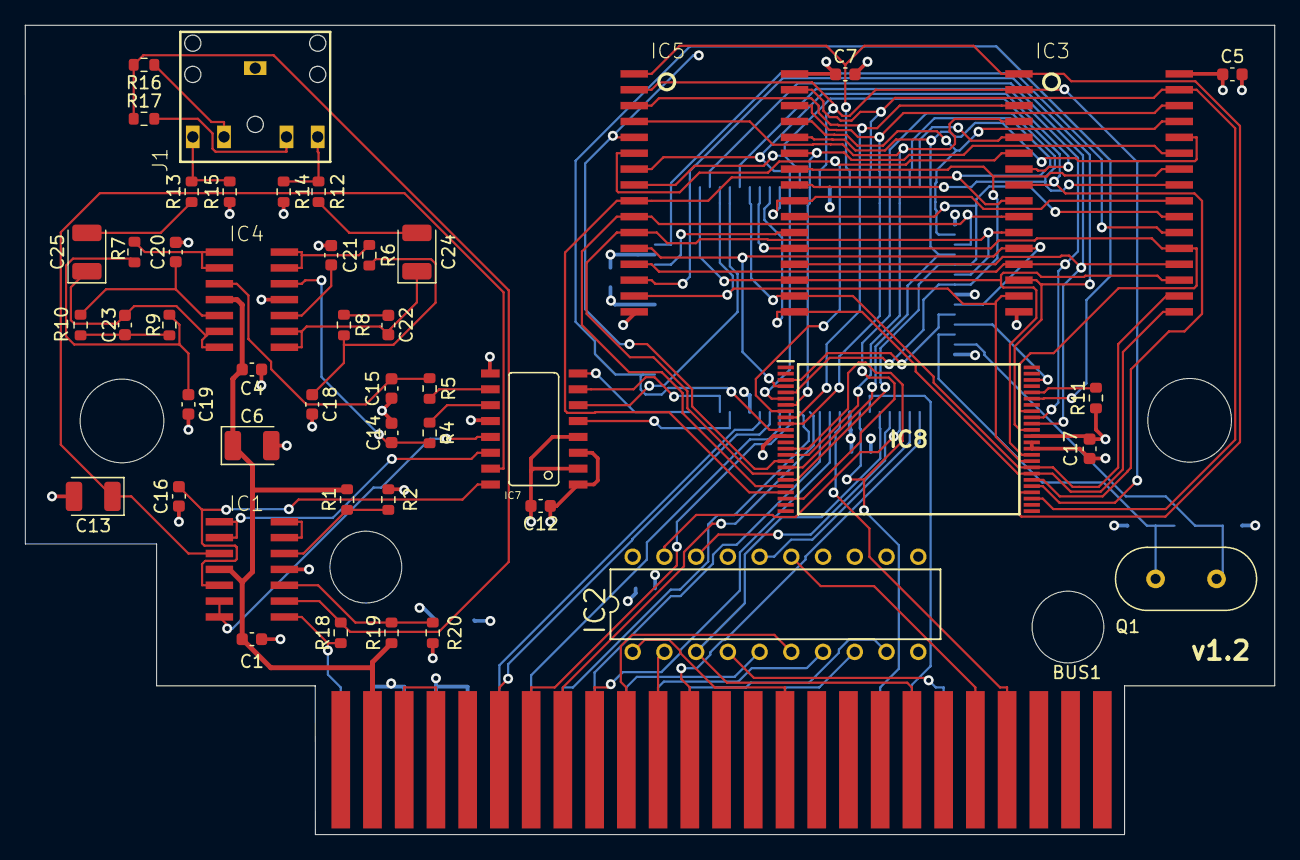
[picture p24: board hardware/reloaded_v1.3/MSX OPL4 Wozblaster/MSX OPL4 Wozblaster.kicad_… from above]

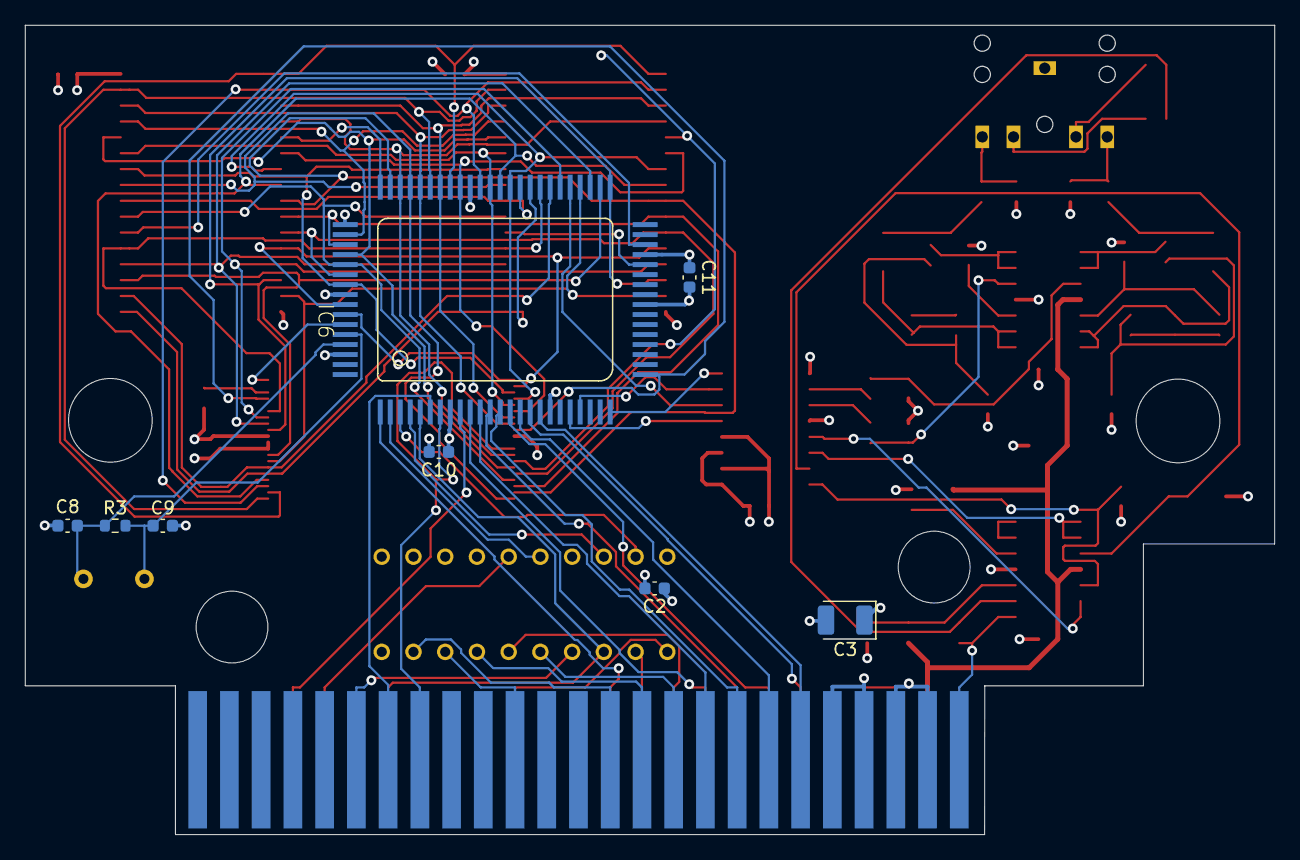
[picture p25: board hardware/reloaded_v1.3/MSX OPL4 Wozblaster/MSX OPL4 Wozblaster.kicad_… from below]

Board: 4 copper layers, 100.0 x 64.8 mm, 56 parts (8 on the bottom side), 99 nets.

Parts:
BUS1: MSX_SLOT_EDGE-CON; msx_cartridge
C1, C2, C4, C5, C7, C10, C11, C12, C17: 0.1uF; C_0603_1608Metric
C3, C13: 10uF/16V; CP_EIA-3528-21_Kemet-B
C6: 220/16; CP_EIA-3528-21_Kemet-B
C8, C9: 12pF; C_0603_1608Metric
C14, C15, C20, C21: 2n2; C_0603_1608Metric
C16: 10p; C_0603_1608Metric
C18, C19: 15nF; C_0603_1608Metric
C22, C23: 3n9; C_0603_1608Metric
C24, C25: 22/16; CP_EIA-3528-21_Kemet-B
IC1, IC4: LF347; SO14-2
IC2: GAL16V8D; DIL20
IC3, IC5: KM684000ALG; SOP32L
IC6: YMF278B-F; 80-QFP
IC7: YAC513-M; 16SOP
IC8: AM29F016B-120EC; SOP50P2000X120-48N
J1: PJ-307
Q1: 33.8688; Crystal_HC49-U_Vertical
R1, R2: 470K; R_0603_1608Metric
R3: 3.3K; R_0603_1608Metric
R4, R5: 360R; R_0603_1608Metric
R6, R7, R8, R9, R10, R11, R12, R13, R16, R17, R18: 1K; R_0603_1608Metric
R14, R15: 100K; R_0603_1608Metric
R19, R20: 10K; R_0603_1608Metric

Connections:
+5V: BUS1.45 (+5V), BUS1.47 (+5V), C2.1, C3.1 (+), C5.1, C7.1, C10.1, C11.1, C12.1, C17.1, IC2.20 (VCC), IC3.32 (VCC), IC5.32 (VCC), IC6.8 (VCC), IC6.32 (VCC@1), IC6.55 (VCC@2), IC6.72 (VCC@3), IC7.1 (VCC), IC7.3 (VCC@1), IC8.12 (VCC_1), IC8.37 (VCC_2), R11.1
+12V: BUS1.48 (+12V), C1.1, C4.1, C6.1 (+), IC1.4 (VCC), IC4.4 (VCC), R1.2, R19.1
/A0: IC3.8 (A4), IC5.8 (A4), IC6.52 (MA0), IC8.30 (A0)
/A1: IC3.2 (A16), IC5.2 (A16), IC6.54 (MA1), IC8.29 (A1)
/A2: IC3.1 (A18), IC5.1 (A18), IC6.57 (MA2), IC8.28 (A2)
/A3: IC3.31 (A15), IC5.31 (A15), IC6.59 (MA3), IC8.27 (A3)
/A4: IC3.25 (A11), IC5.25 (A11), IC6.61 (MA4), IC8.22 (A4)
/A5: IC3.9 (A3), IC5.9 (A3), IC6.63 (MA5), IC8.21 (A5)
/A6: IC3.10 (A2), IC5.10 (A2), IC6.67 (MA6), IC8.20 (A6)
/A7: IC3.23 (A10), IC5.23 (A10), IC6.69 (MA7), IC8.19 (A7)
/A8: IC3.11 (A1), IC5.11 (A1), IC6.70 (MA8), IC8.18 (A8)
/A9: IC3.28 (A13), IC5.28 (A13), IC6.68 (MA9), IC8.17 (A9)
/A10: IC3.5 (A7), IC5.5 (A7), IC6.64 (MA10), IC8.16 (A10)
/A11: IC3.4 (A12), IC5.4 (A12), IC6.62 (MA11), IC8.15 (A11)
/A12: IC3.30 (A17), IC5.30 (A17), IC6.60 (MA12), IC8.10 (A12)
/A13: IC3.3 (A14), IC5.3 (A14), IC6.58 (MA13), IC8.9 (A13)
/A14: IC3.6 (A6), IC5.6 (A6), IC6.56 (MA14), IC8.8 (A14)
/A15: IC3.27 (A8), IC5.27 (A8), IC6.53 (MA15), IC8.7 (A15)
/A16: IC3.7 (A5), IC5.7 (A5), IC6.51 (MA16), IC8.6 (A16)
/A17: IC3.26 (A9), IC5.26 (A9), IC6.71 (MA17), IC8.5 (A17)
/A18: IC3.12 (A0), IC5.12 (A0), IC6.73 (MA18), IC8.4 (A18)
/A19: IC6.74 (MA19), IC8.3 (A19)
/A20: IC6.75 (MA20), IC8.46 (A20)
/AA0: BUS1.28 (A0), IC6.1 (A0)
/AA1: BUS1.27 (A1), IC2.9 (I8)
/AA2: BUS1.30 (A2), IC2.2 (I1)
/AA3: BUS1.29 (A3), IC2.7 (I6)
/AA4: BUS1.32 (A4), IC2.6 (I5)
/AA5: BUS1.31 (A5), IC2.5 (I4)
/AA6: BUS1.22 (A6), IC2.1 (CLK)
/AA7: BUS1.21 (A7), IC2.8 (I7)
/D0: BUS1.34 (D0), IC6.10 (D0)
/D1: BUS1.33 (D1), IC6.11 (D1)
/D2: BUS1.36 (D2~), IC6.12 (D2)
/D3: BUS1.35 (D3), IC6.13 (D3)
/D4: BUS1.38 (D4), IC6.14 (D4)
/D5: BUS1.37 (D5), IC6.15 (D5)
/D6: BUS1.40 (D6), IC6.16 (D6)
/D7: BUS1.39 (D7), IC6.17 (D7)
/MD0: IC3.17 (O4), IC5.17 (O4), IC6.49 (MD0), IC8.31 (DQ0)
/MD1: IC3.18 (O5), IC5.18 (O5), IC6.47 (MD1), IC8.32 (DQ1)
/MD2: IC3.15 (O3), IC5.15 (O3), IC6.44 (MD2), IC8.33 (DQ2)
/MD3: IC3.19 (O6), IC5.19 (O6), IC6.42 (MD3), IC8.34 (DQ3)
/MD4: IC3.14 (O2), IC5.14 (O2), IC6.41 (MD4), IC8.38 (DQ4)
/MD5: IC3.20 (O7), IC5.20 (O7), IC6.43 (MD5), IC8.39 (DQ5)
/MD6: IC3.13 (O1), IC5.13 (O1), IC6.46 (MD6), IC8.40 (DQ6)
/MD7: IC3.21 (O8), IC5.21 (O8), IC6.48 (MD7), IC8.41 (DQ7)
/SLTSOUND: BUS1.49 (SOUNDOUT), IC1.8 (OUT), R18.1
/~BUSDIR: BUS1.10 (~BUSDIR), IC2.15 (O5)
/~CS0: IC5.22 (~CS), IC6.36 (~MCS6)
/~CS1: IC3.22 (~CS), IC6.38 (~MCS7)
/~INT: BUS1.8 (~INT), IC6.9 (~IRQ)
/~IORQ: BUS1.11 (~IORQ), IC2.4 (I3)
/~MRD: IC3.24 (~OE), IC5.24 (~OE), IC6.50 (~MRD)
/~MWR: IC3.29 (~WE), IC5.29 (~WE), IC6.66 (~MWR)
/~RD: BUS1.14 (~RD), IC2.3 (I2), IC6.5 (~RD)
/~RESET: BUS1.15 (~RESET), IC6.7 (~RESET), IC8.14 (RESET#)
/~ROM: IC6.25 (~MCS0), IC8.11 (CE#), IC8.43 (OE#)
/~WR: BUS1.13 (~WR), IC6.6 (~WR)
GND: BUS1.41 (GND), BUS1.43 (GND), C1.2, C2.2, C3.2 (-), C4.2, C5.2, C6.2 (-), C7.2, C8.2, C9.2, C10.2, C11.2, C12.2, C13.2 (-), C14.2, C15.2, C16.1, C17.2, C18.2, C19.2, C20.2, C21.2, IC1.11 (GND), IC2.10 (GND), IC2.11 (~OE), IC2.12 (O8), IC2.13 (O7), IC2.14 (O6), IC2.17 (O3), IC3.16 (GND), IC4.11 (GND), IC5.16 (GND), IC6.18 (GND), IC6.37 (GND@1), IC6.65 (GND@2), IC6.78 (GND@3), IC7.2 (GND), IC7.4 (SEL), IC7.9 (TST1), IC7.12 (TST2), IC8.35 (VSS_1), IC8.36 (VSS_2), J1.1, R2.1, R14.1, R15.1, R20.1
unnamed: BUS1.44 (SW1), BUS1.46 (SW2)
unnamed: C13.1 (+), IC1.3 (IN+), IC7.15 (CV)
unnamed: C18.1, R6.2, R8.1
unnamed: C19.1, R7.2, R9.2
unnamed: C22.1, R8.2
unnamed: C23.1, R9.1, R10.2
unnamed: C22.2, C24.1 (+), IC4.8 (OUT), IC4.9 (IN-)
unnamed: C24.2 (-), R12.1
unnamed: C23.2, C25.1 (+), IC4.6 (IN-), IC4.7 (OUT)
unnamed: C25.2 (-), R13.1
unnamed: IC1.1 (OUT), IC1.2 (IN-), IC7.14 (MP)
unnamed: C16.2, IC1.5 (IN+), IC7.16 (AOUT)
unnamed: IC1.6 (IN-), IC1.7 (OUT), IC7.13 (SWIN)
unnamed: IC1.10 (IN+), R19.2, R20.2
unnamed: IC1.9 (IN-), R16.2, R17.1, R18.2
unnamed: IC1.12 (IN+), R1.1, R2.2
unnamed: IC1.13 (IN-), IC1.14 (OUT)
unnamed: IC2.19 (O1), IC6.3 (A2)
unnamed: IC2.18 (O2), IC6.4 (~CS)
unnamed: IC2.16 (O4), IC6.2 (A1)
unnamed: C15.1, IC4.3 (IN+), R5.2
unnamed: IC4.1 (OUT), IC4.2 (IN-), R7.1
unnamed: C20.1, IC4.5 (IN+), R10.1
unnamed: C21.1, IC4.10 (IN+)
unnamed: C14.1, IC4.12 (IN+), R4.2
unnamed: IC4.13 (IN-), IC4.14 (OUT), R6.1
unnamed: IC6.20 (BCO), IC7.5 (CLK)
unnamed: IC6.24 (DO2), IC7.8 (DIN)
unnamed: IC6.21 (LRO), IC7.7 (LRCK)
unnamed: IC6.45 (WCO), IC7.6 (WDCK)
unnamed: C8.1, IC6.77 (XI), Q1.2, R3.1
unnamed: C9.1, IC6.76 (XO), Q1.1, R3.2
unnamed: IC7.10 (CH1), R5.1
unnamed: IC7.11 (CH2), R4.1
unnamed: IC8.44 (WE#), R11.2
unnamed: J1.2, R12.2, R14.2
unnamed: J1.3, R17.2
unnamed: J1.4, R16.1
unnamed: J1.5, R13.2, R15.2

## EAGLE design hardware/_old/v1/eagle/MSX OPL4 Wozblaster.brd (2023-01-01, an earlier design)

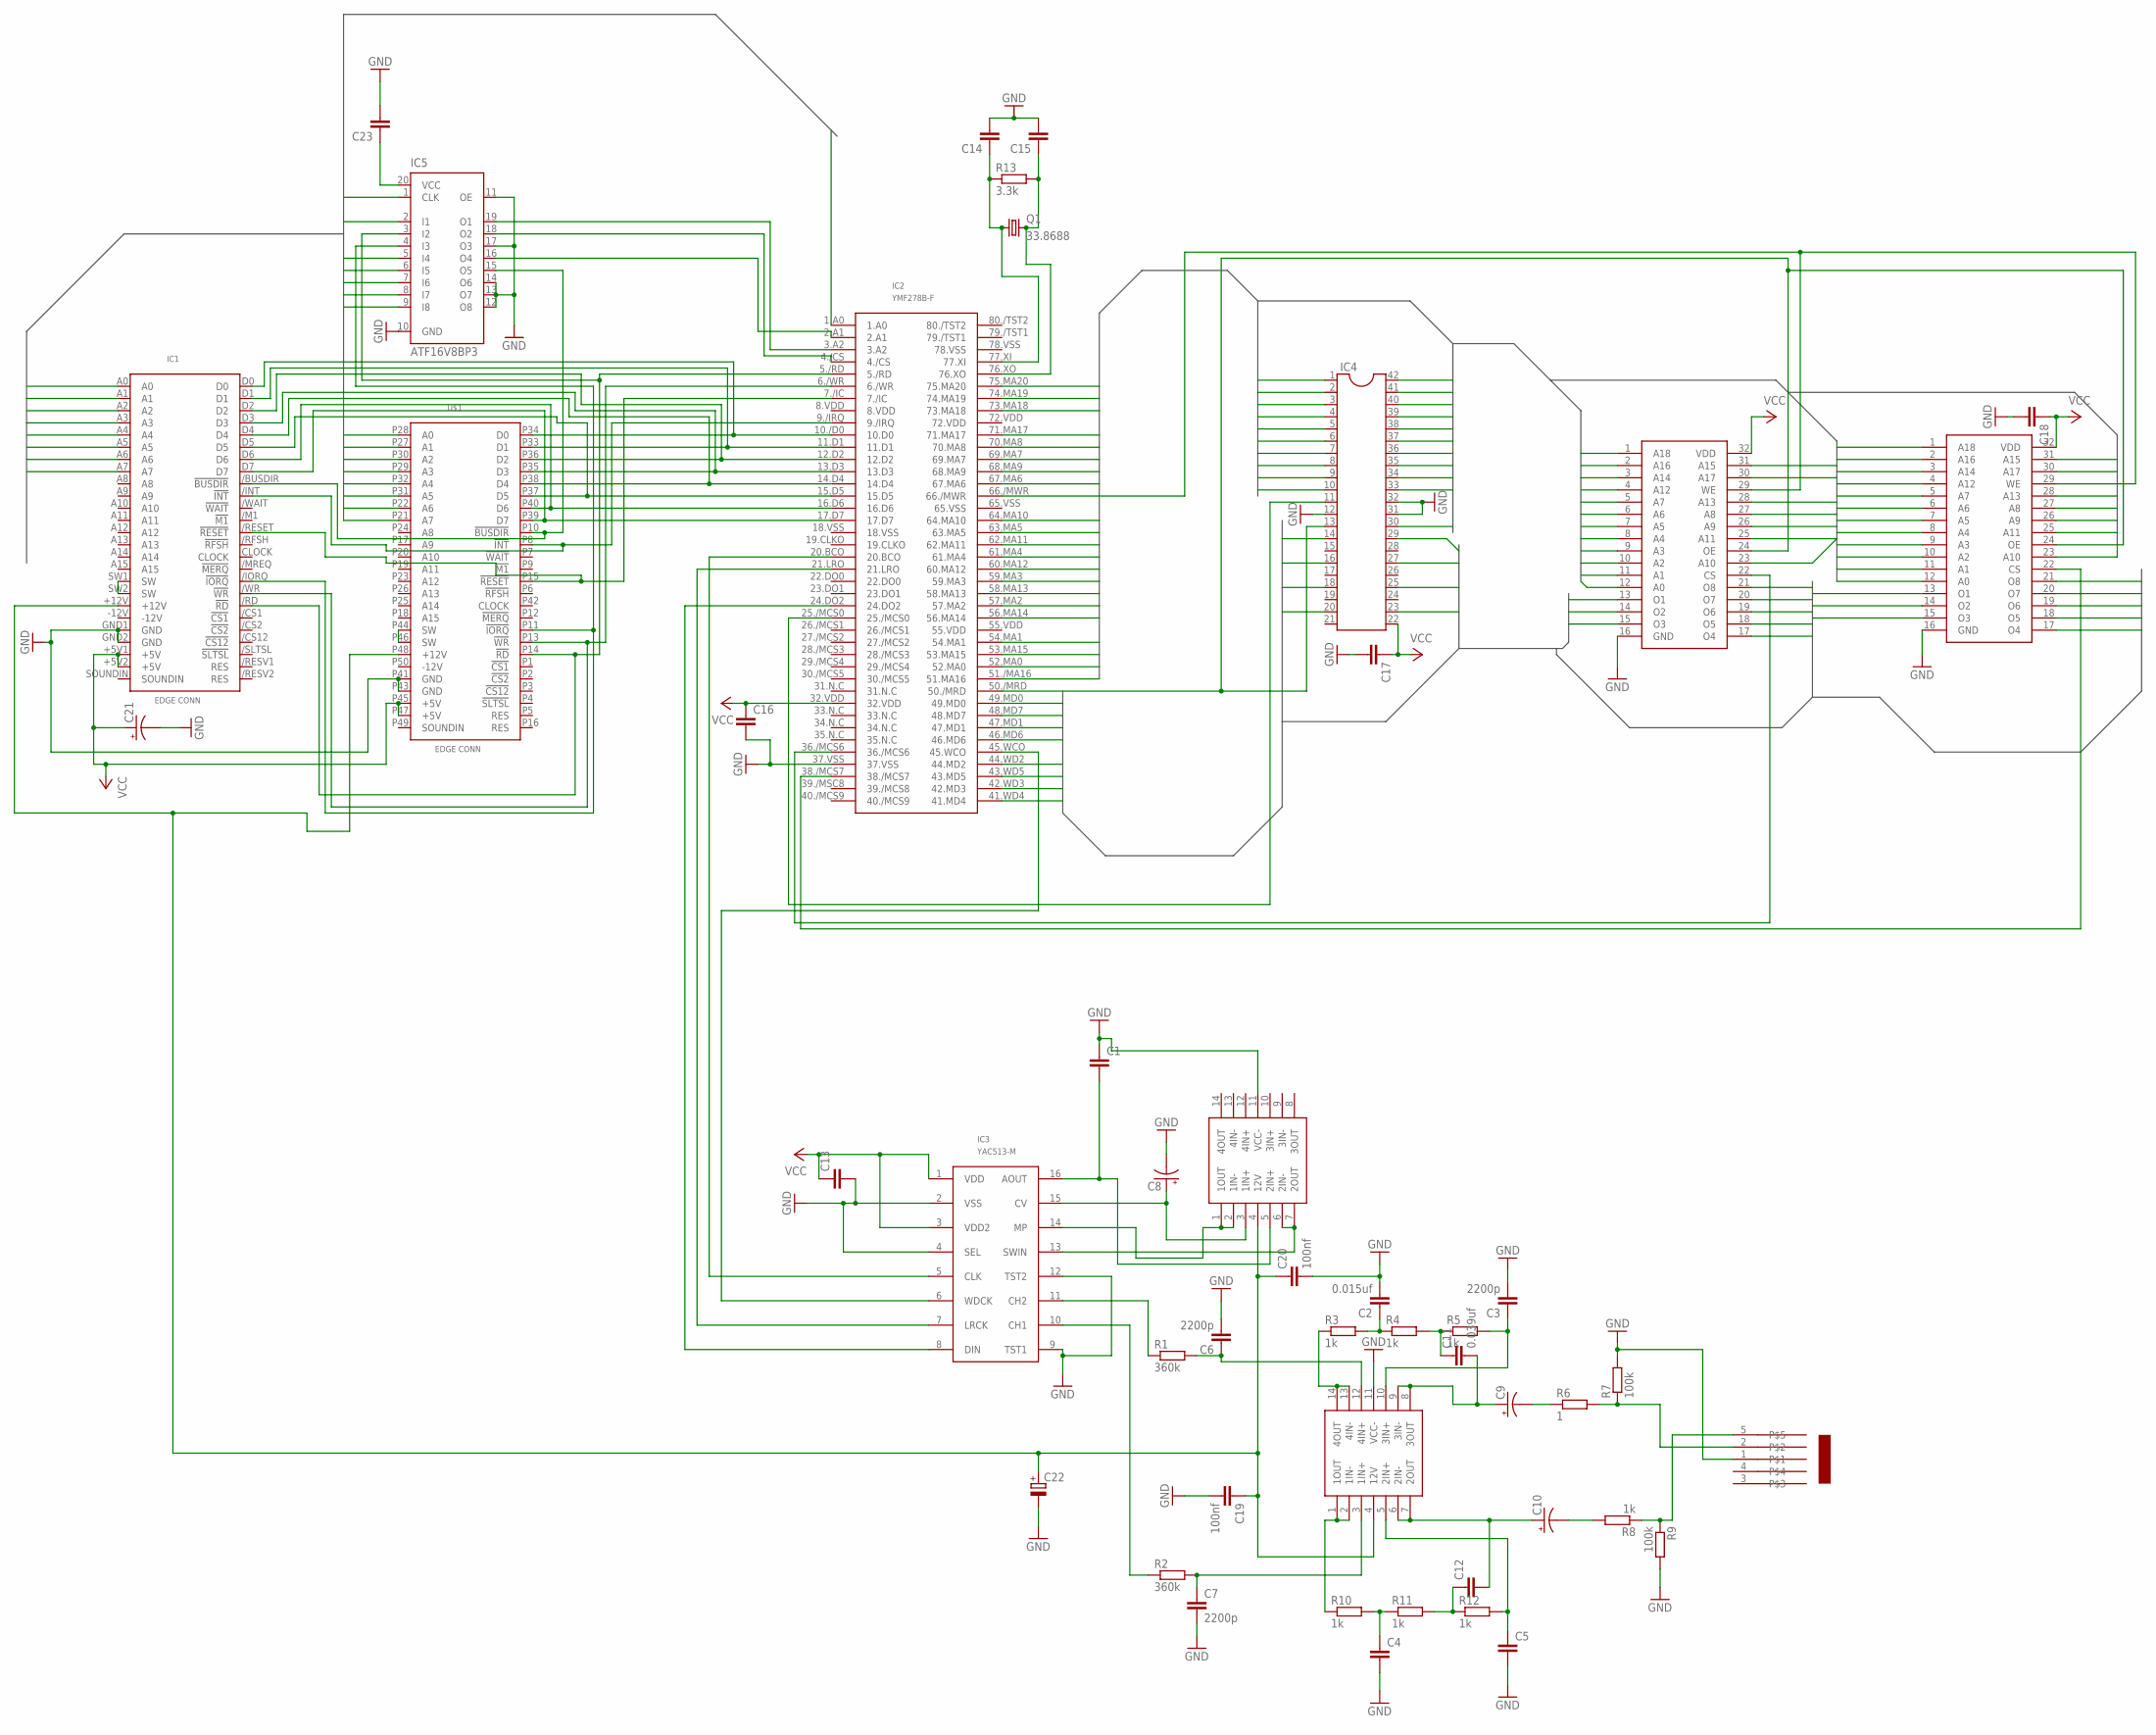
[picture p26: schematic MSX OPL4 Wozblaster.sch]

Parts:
C1, C4, C5, C12, C13, C14, C15, C16, C17, C18, C23: C2.5/2; C2.5-2
C2: 0.015uf; C2.5-2
C3, C6, C7: 2200p; C2.5-2
C8, C9, C10, C21: CPOL-USE2.5-5; E2,5-5
C11: 0.039uf; C2.5-2
C19, C20: 100nf; C2.5-2
C22: CPOL-EUD/7343-31R; D/7343-31R
IC1: OPL4_10X10; OPL410X10
IC2: YMF278B-F; 80-QFP
IC3: YAC513-M; 16SOP
IC4: DIL42
IC5: ATF16V8BP3; DIL20
Q1: 33.8688; HC49/S
R1, R2: 360k; 0204/7
R3, R4, R5, R8, R10, R11, R12: 1k; 0204/7
R6: 1; 0204/7
R7, R9: 100k; 0204/7
R13: 3.3k; 0204/7
U$1: 50PINCONN; MSX50PINHEADER
U$2, U$3: LF347SO14; SO14-2
U$4, U$5: SRAM4MBIT; SOP32L
U$6: MSXJACK; 1501_06

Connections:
+12V: C19.1, C20.1, C22.+, IC1.+12V, U$1.P48 (+12V), U$2.4 (12V), U$3.4 (12V)
A0: IC2.52.MA0, IC4.30 (MA0), U$4.12 (A0), U$5.12 (A0)
A1: IC2.54.MA1, IC4.10 (MA1), U$4.11 (A1), U$5.11 (A1)
A2: IC2.57.MA2, IC4.9 (MA2), U$4.10 (A2), U$5.10 (A2)
A3: IC2.59.MA3, IC4.8 (MA3), U$4.9 (A3), U$5.9 (A3)
A4: IC2.61.MA4, IC4.7 (MA4), U$4.8 (A4), U$5.8 (A4)
A5: IC2.63.MA5, IC4.6 (MA5), U$4.7 (A5), U$5.7 (A5)
A6: IC2.67.MA6, IC4.5 (MA6), U$4.6 (A6), U$5.6 (A6)
A7: IC2.69.MA7, IC4.4 (MA7), U$4.5 (A7), U$5.5 (A7)
A8: IC2.70.MA8, IC4.3 (MA8), U$4.27 (A8), U$5.27 (A8)
A9: IC2.68.MA9, IC4.41 (MA9), U$4.26 (A9), U$5.26 (A9)
A10: IC2.64.MA10, IC4.40 (MA10), U$4.23 (A10), U$5.23 (A10)
A11: IC2.62.MA11, IC4.39 (MA11), U$4.25 (A11), U$5.25 (A11)
A12: IC2.60.MA12, IC4.38 (MA12), U$4.4 (A12), U$5.4 (A12)
A13: IC2.58.MA13, IC4.37 (MA13), U$4.28 (A13), U$5.28 (A13)
A14: IC2.56.MA14, IC4.36 (MA14), U$4.3 (A14), U$5.3 (A14)
A15: IC2.53.MA15, IC4.35 (MA15), U$4.31 (A15), U$5.31 (A15)
A16: IC2.51./MA16 (51.MA16), IC4.34 (MA16), U$4.2 (A16), U$5.2 (A16)
A17: IC2.71.MA17, IC4.33 (MA17), U$4.30 (A17), U$5.30 (A17)
A18: IC2.73.MA18, IC4.2 (MA18), U$4.1 (A18), U$5.1 (A18)
A19: IC2.74.MA19, IC4.1 (MA19)
A20: IC2.75.MA20, IC4.42 (MA20)
AA0: IC1.A0, IC2.1.A0, U$1.P28 (A0)
AA1: IC1.A1, IC5.9 (I8), U$1.P27 (A1)
AA2: IC1.A2, IC5.2 (I1), U$1.P30 (A2)
AA3: IC1.A3, IC5.7 (I6), U$1.P29 (A3)
AA4: IC1.A4, IC5.6 (I5), U$1.P32 (A4)
AA5: IC1.A5, IC5.5 (I4), U$1.P31 (A5)
AA6: IC1.A6, IC5.1 (CLK), U$1.P22 (A6)
AA7: IC1.A7, IC5.8 (I7), U$1.P21 (A7)
GND: C1.1, C2.2, C3.2, C4.2, C5.2, C6.2, C7.2, C8.-, C13.2, C14.2, C15.2, C16.2, C17.2, C18.2, C19.2, C20.2, C21.-, C22.-, C23.2, IC1.GND1 (GND), IC1.GND2 (GND), IC2.37.VSS, IC3.2 (VSS), IC3.4 (SEL), IC3.9 (TST1), IC3.12 (TST2), IC4.12 (VSS), IC4.31 (GND1), IC4.32 (GND), IC5.10 (GND), IC5.11 (OE), IC5.12 (O8), IC5.13 (O7), IC5.14 (O6), IC5.17 (O3), R7.2, R9.2, U$1.P41 (GND), U$1.P43 (GND), U$2.11 (VCC-), U$3.11 (VCC-), U$4.16 (GND), U$5.16 (GND), U$6.1
MD0: IC2.49.MD0, IC4.14 (MD0), U$4.13 (O1), U$5.13 (O1)
MD1: IC2.47.MD1, IC4.16 (MD1), U$4.14 (O2), U$5.14 (O2)
MD2: IC2.44.WD2 (44.MD2), IC4.18 (MD2), U$4.15 (O3), U$5.15 (O3)
MD3: IC2.42.WD3 (42.MD3), IC4.20 (MD3), U$4.17 (O4), U$5.17 (O4)
MD4: IC2.41.WD4 (41.MD4), IC4.23 (MD4), U$4.18 (O5), U$5.18 (O5)
MD5: IC2.43.WD5 (43.MD5), IC4.25 (MD5), U$4.19 (O6), U$5.19 (O6)
MD6: IC2.46.MD6, IC4.27 (MD6), U$4.20 (O7), U$5.20 (O7)
MD7: IC2.48.MD7, IC4.29 (MD7), U$4.21 (O8), U$5.21 (O8)
unnamed: IC1.D0, IC2.10./D0 (10.D0), U$1.P34 (D0)
unnamed: IC1.D1, IC2.11.D1, U$1.P33 (D1)
unnamed: IC1.D2, IC2.12.D2, U$1.P36 (D2)
unnamed: IC1.D3, IC2.13.D3, U$1.P35 (D3)
unnamed: IC1.D4, IC2.14.D4, U$1.P38 (D4)
unnamed: IC1.D5, IC2.15.D5, U$1.P37 (D5)
unnamed: IC1.D6, IC2.16.D6, U$1.P40 (D6)
unnamed: IC1.D7, IC2.17.D7, U$1.P39 (D7)
unnamed: IC1./RD (!RD), IC2.5./RD, IC5.3 (I2), U$1.P14 (!RD)
unnamed: IC1./IORQ (!IORQ), IC5.4 (I3), U$1.P11 (!IORQ)
unnamed: IC2.3.A2, IC5.19 (O1)
unnamed: IC2.4./CS, IC5.18 (O2)
unnamed: IC2.2.A1, IC5.16 (O4)
unnamed: IC1./BUSDIR (!BUSDIR), IC5.15 (O5), U$1.P10 (!BUSDIR)
unnamed: C1.2, IC3.16 (AOUT), U$2.5 (2IN+)
unnamed: IC3.14 (MP), U$2.1 (1OUT), U$2.2 (1IN-)
unnamed: IC3.11 (CH2), R1.1
unnamed: C6.1, R1.2, U$3.12 (4IN+)
unnamed: R3.1, U$3.13 (4IN-), U$3.14 (4OUT)
unnamed: C2.1, R3.2, R4.1
unnamed: C11.1, R4.2, R5.1
unnamed: C3.1, R5.2, U$3.10 (3IN+)
unnamed: C9.+, C11.2, U$3.8 (3OUT), U$3.9 (3IN-)
unnamed: C10.-, R8.2
unnamed: R6.2, R7.1, U$6.2
unnamed: C7.1, R2.2, U$3.3 (1IN+)
unnamed: R10.1, U$3.1 (1OUT), U$3.2 (1IN-)
unnamed: C4.1, R10.2, R11.1
unnamed: C12.1, R11.2, R12.1
unnamed: C5.1, R12.2, U$3.5 (2IN+)
unnamed: C10.+, C12.2, U$3.6 (2IN-), U$3.7 (2OUT)
unnamed: C9.-, R6.1
unnamed: R8.1, R9.1, U$6.5
unnamed: IC3.10 (CH1), R2.1
unnamed: C8.+, IC3.15 (CV), U$2.3 (1IN+)
unnamed: IC3.13 (SWIN), U$2.6 (2IN-), U$2.7 (2OUT)
unnamed: IC2.20.BCO, IC3.5 (CLK)
unnamed: IC2.45.WCO, IC3.6 (WDCK)
unnamed: IC2.21.LRO, IC3.7 (LRCK)
unnamed: IC2.24.DO2, IC3.8 (DIN)
unnamed: C15.1, IC2.76.XO, Q1.2, R13.2
unnamed: C14.1, IC2.77.XI, Q1.1, R13.1
unnamed: IC2.25./MCS0, IC4.11 (MCS0)
unnamed: IC2.50./MRD, IC4.13 (MRD), U$4.24 (OE), U$5.24 (OE)
unnamed: IC2.36./MCS6, U$4.22 (CS)
unnamed: IC2.38./MCS7, U$5.22 (CS)
unnamed: IC2.66./MWR, U$4.29 (WE), U$5.29 (WE)
unnamed: IC1.SW1 (SW), IC1.SW2 (SW)
unnamed: U$1.P44 (SW), U$1.P46 (SW)
unnamed: IC1./WR (!WR), IC2.6./WR, U$1.P13 (!WR)
unnamed: IC1./INT (!INT), IC2.9./IRQ, U$1.P8 (!INT)
unnamed: IC1./RESET (!RESET), IC2.7./IC, U$1.P15 (!RESET)
unnamed: C23.1, IC5.20 (VCC)
VCC: C13.1, C16.1, C17.1, C18.1, C21.+, IC1.+5V1 (+5V), IC1.+5V2 (+5V), IC2.32.VDD, IC3.1 (VDD), IC3.3 (VDD2), IC4.22 (VDD), U$1.P45 (+5V), U$1.P47 (+5V), U$4.32 (VDD), U$5.32 (VDD)

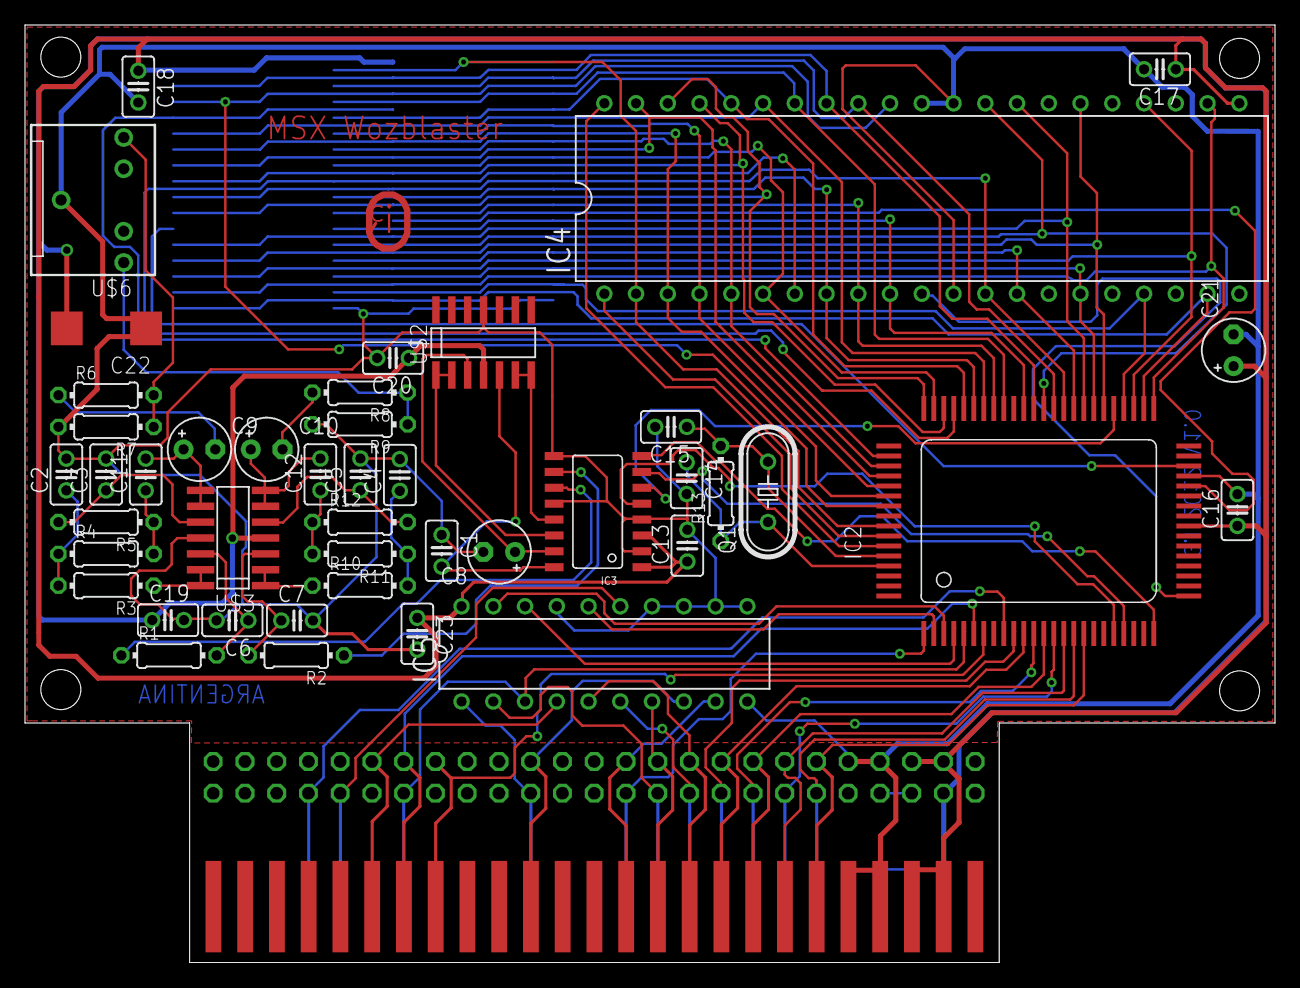
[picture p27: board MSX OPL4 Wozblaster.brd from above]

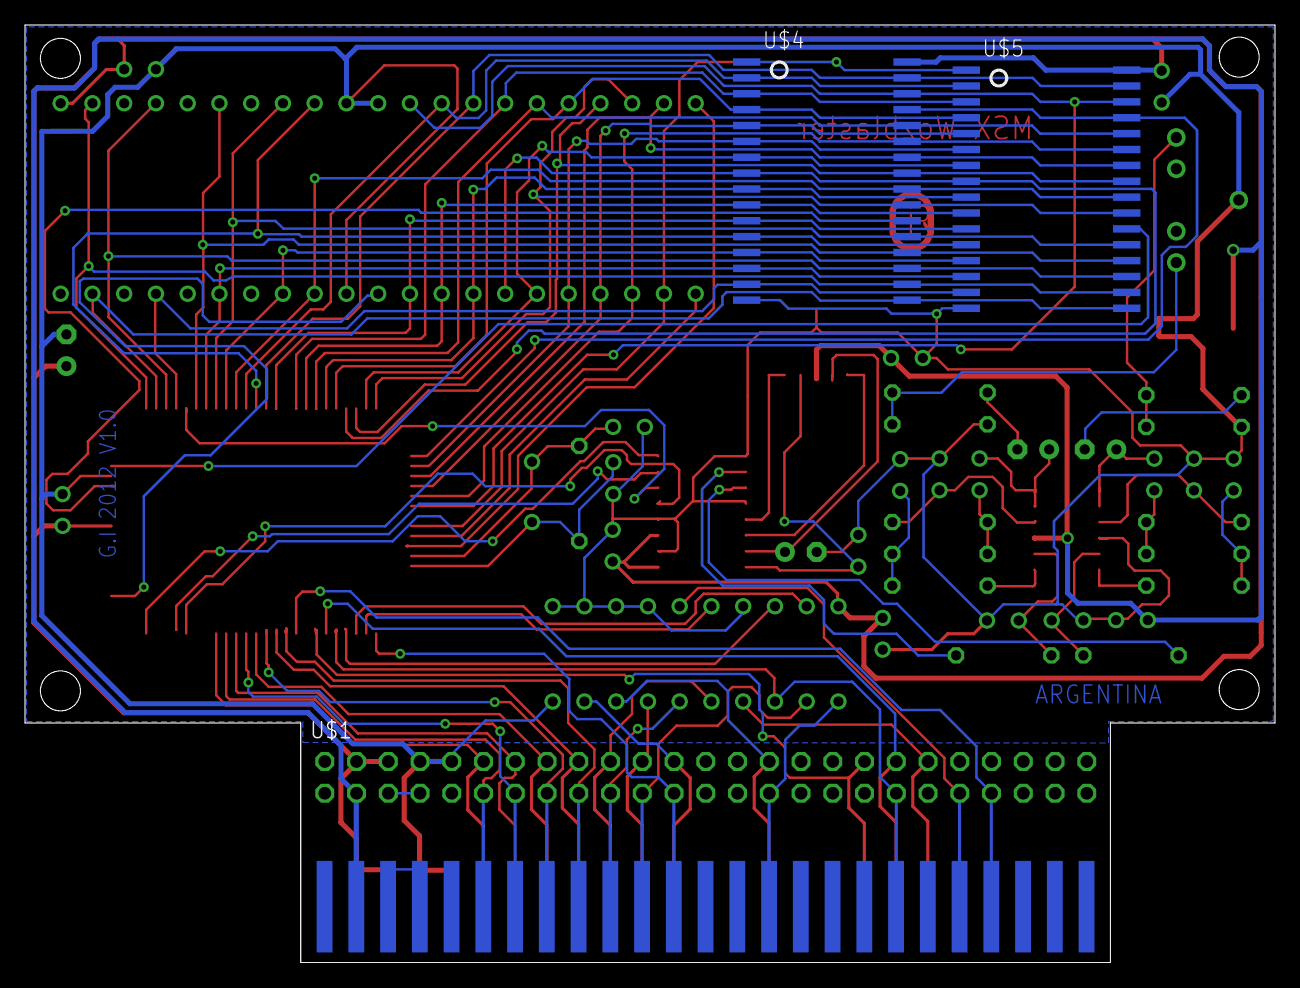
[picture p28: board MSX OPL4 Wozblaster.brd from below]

Board: 2 copper layers, 100.0 x 75.0 mm, 48 parts (4 on the bottom side), 93 nets.

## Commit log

2023-01-01 hardware folder
    [MSX OPL4 Wozblaster-B_Cu.gbr, MSX OPL4 Wozblaster-B_Mask.gbr, MSX OPL4 Wozblaster-B_Paste.gbr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]
2023-01-01 adapter to program the eprom
    [27C160_Adapter-B.Mask.gbr, 27C160_Adapter-B.Paste.gbr, 27C160_Adapter-B.SilkS.gbr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]
2023-01-02 fixes to the PCB
    [bom.csv, designators.csv, positions.csv]
2023-01-02 save project kicad
2023-01-02 soundin version
    [MSX OPL4 Wozblaster-B_Cu.gbr, MSX OPL4 Wozblaster-B_Mask.gbr, MSX OPL4 Wozblaster-B_Paste.gbr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]
2023-01-02 case for the wozblaster v1
    [Wozblaster V1 - bottom_v1.0.stl, Wozblaster V1 - top_v1.0.stl]
2023-01-03 iteractions of the case
    [Wozblaster V1 1.1_bottom.stl, Wozblaster V1 1.1_top.stl, Wozblaster V1 1.2_bottom.stl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]
2023-01-20 conversion fixes
    [MSX OPL4 Wozblaster.kicad_sch]
2023-02-20 v1.2 and v2 work in progress
    [MSX OPL4 Wozblaster.dsn, MSX OPL4 Wozblaster.kicad_pcb, MSX OPL4 Wozblaster.kicad_sch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]
2023-02-20 Text Improvements
    [MSX OPL4 Wozblaster.kicad_pcb, MSX OPL4 Wozblaster.kicad_sch, bom.csv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]
2023-02-20 PCB image
2023-02-20 Uploading Gerbers vor v1.2
    [MSX OPL4 Wozblaster.kicad_pcb, bom.csv, designators.csv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]
2023-03-22 v3 and multiple adjusts
    [MSX OPL4 Wozblaster.kicad_pcb, MSX OPL4 Wozblaster.kicad_sch, bom.csv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]
2023-04-21 Reloaded 3.1
    [MSX OPL4 Wozblaster.kicad_sch, bom.csv, designators.csv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]
2023-04-21 footprints for 3.1
2023-06-06 v3.3 update
    [MSX OPL4 Wozblaster.kicad_sch, bom.csv, designators.csv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]
2023-06-06 footprint adjustments
2023-08-27 v4.0 upload and README adjustments
    [MSX OPL4 Wozblaster.kicad_sch, bom.csv, designators.csv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]
2023-09-24 Footprint adjustments, README, small fixes
    [MSX OPL4 Wozblaster.kicad_sch, bom.csv, designators.csv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]
2024-10-13 v5.0 initial upload
    [MSX OPL4 Wozblaster.kicad_sch, bom.csv, designators.csv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]
2024-11-18 cpld code and pcb adjustments after tests
    [MSX OPL4 Wozblaster.kicad_sch, bom.csv, designators.csv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]
2025-01-01 README.MD update
    [MSX OPL4 Wozblaster.brd, MSX OPL4 Wozblaster.sch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]
